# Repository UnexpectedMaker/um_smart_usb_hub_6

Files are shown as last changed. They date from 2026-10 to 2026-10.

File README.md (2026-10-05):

# Smart 6 Port USB Hub

**Automated testing. Automated device control.**

**Designed and made by [Unexpected Maker](https://unexpectedmaker.com) ·
[Get one from the store →](https://unexpectedmaker.com/shop/smarthub)**

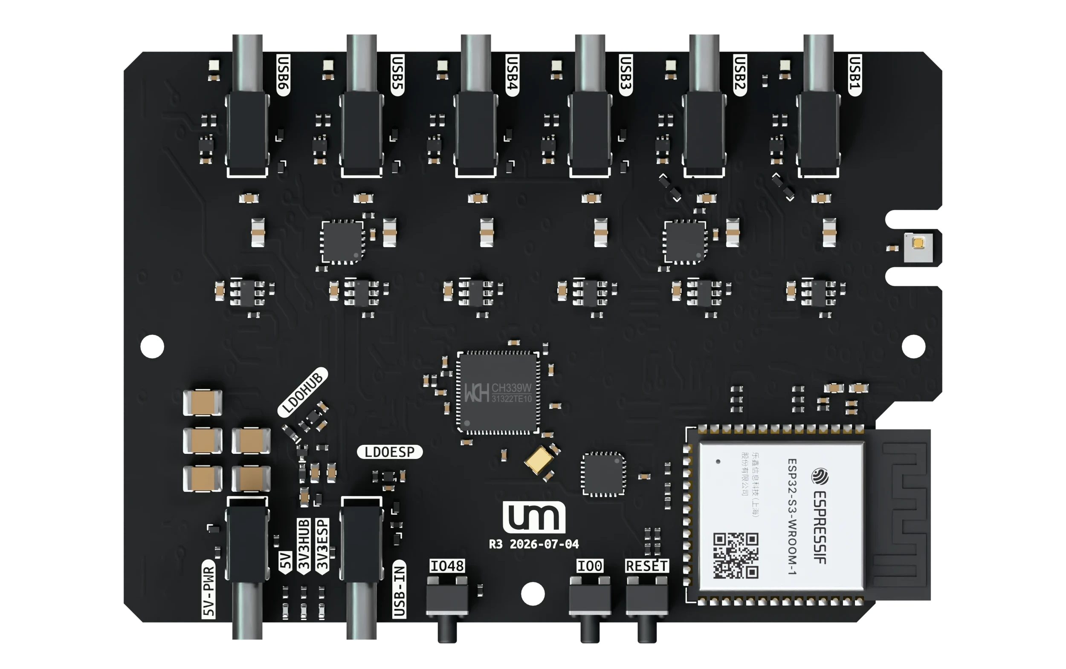
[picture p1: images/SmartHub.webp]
Smart 6 Port USB Hub


Built for developers, test benches and USB devices that need to run unattended.
Smart USB Hub brings repeatable testing and everyday device routines to your
workbench, without the constant plugging, unplugging and reaching for cables.

## What it does

**Power cycling, scripted.** Use the REST API to switch a device's power, read
its voltage, current and power consumption, and check port status from your
test scripts. Repeat a startup test or compare readings across operating states
while the other devices stay powered.

**Every port, scheduled.** Set a different schedule for each port: selected
weekdays, a fixed run time, a chosen stop time or repeating intervals. Rules run
on the hub, so your browser doesn't need to stay open.

**Step in any time.** Open the web interface over Wi-Fi to switch an individual
port or investigate a device. Live readings show what it's drawing; connection
and fault status help you see why it isn't behaving as expected.

## Specifications

| | |
|---|---|
| Downstream | 6 × USB-C · USB 2.0 |
| Upstream | 1 × USB-C · USB 2.0 |
| Controller | ESP32-S3-WROOM-1 · 16 MB flash · 8 MB PSRAM |
| Port power | 5V USB-C input · 3A+ supply |
| 3V3 power | 2 × 3.3V LDOs · headroom for the ESP32-S3, hub chip, peripherals and LEDs |
| Protection | Per-port current limiting and over-current fault detection |
| Monitoring | Per-port voltage, current and power |
| Indicators | Per-port RGB status · power, device presence and faults |
| Environment | Onboard temperature and humidity sensor |
| Buttons | IO48 user button · IO0 / Boot · Reset |

## It's open source

Smart USB Hub is fully open source, so you can see exactly how it works, tweak
it to suit your bench, or build your own. Everything is in this repository:

| Folder | Contents |
|---|---|
| [`firmware/`](firmware/) | The PlatformIO project — building, flashing, first-time Wi-Fi setup and how to use the hub |
| [`hardware/`](hardware/) | KiCad 10 design files: schematic, PCB, footprints, 3D models and interactive BOM |
| [`docs/`](docs/) | Documentation: the [JSON / REST API reference](docs/rest_api.md) and [planned future updates](docs/future_updates.md) |
| [`step/`](step/) | STEP models of the board and the case, the light pipe insert, and the parts list for printing your own case |

Each folder has its own README with the details.

## Optional case

Add the case from the [store](https://unexpectedmaker.com/shop/smarthub) and
your hub goes from bare board to finished desk tool:

- **Matt black ABS** — a 3D printed enclosure that looks right at home on any
  bench
- **Laser cut light pipes** — every port's RGB status still shines through
- **Heat inserts + screws** — proper threads, so it goes together solid
- **Rubber feet** — it stays put when you plug and unplug

Or print your own from the files in [`step/`](step/) — its README covers the
light pipe insert and the screws, inserts and feet you'll need.

## Getting started

If you have a hub, start with **First-time setup** in the
[firmware README](firmware/README.md#first-time-setup). It gets the hub onto
your Wi-Fi so you can use the web interface.

## Licence

Copyright (c) 2026 [Unexpected Maker](https://unexpectedmaker.com).

| Part | Licence |
|---|---|
| Hardware (`hardware/`) and 3D files (`step/`) | [CERN-OHL-S v2](hardware/LICENSE) — strongly reciprocal: if you distribute the design, a modified version, or hardware made from it, you must publish the complete design source under the same licence |
| Firmware (`firmware/`) | [GPL-3.0-or-later](firmware/LICENSE) — use it, change it, put it in your own products; if you distribute it, you must publish the complete firmware source under the same licence. Bundled third-party code keeps its own licence (see the [firmware README](firmware/README.md#third-party-code)) |

Source location: <https://github.com/UnexpectedMaker/um_smart_usb_hub_6>

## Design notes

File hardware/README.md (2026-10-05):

# Hardware

KiCad 10 project for the Unexpected Maker 6 Port Smart USB Hub (R3).

Open `UM 6 Port USB HUB R3/UM 6 Port USB HUB R3.kicad_pro` in KiCad 10 or later.

## Self-contained project

Everything that is not part of a standard KiCad installation is included in the project folder. No external or personal libraries are needed, and there are no absolute paths in any project file.

- **Footprints** – every non-stock footprint used on the board lives in the project library `UM_Hub.pretty`. It is registered through the project `fp-lib-table` using `${KIPRJMOD}`, so KiCad picks it up automatically when the project is opened.
- **3D models** – every non-stock model is in `3d models/` and is referenced relative to the project (`${KIPRJMOD}/3d models/...`). The 0805 resistor model is embedded in its footprint.
- **Stock parts** – the remaining footprints and models come from the default libraries installed with KiCad (`Capacitor_SMD`, `Package_DFN_QFN`, `Package_TO_SOT_SMD`, `RF_Module`, `MountingHole` and the standard `KICAD*_3DMODEL_DIR` models).
- **Symbols** – the schematic carries its own copy of every symbol it uses, so it opens and edits without any external symbol libraries.

## Contents of `UM 6 Port USB HUB R3/`

| Item | What it is |
|---|---|
| `UM 6 Port USB HUB R3.kicad_pro` | KiCad project file |
| `UM 6 Port USB HUB R3.kicad_sch` | Schematic |
| `UM 6 Port USB HUB R3.kicad_pcb` | PCB layout |
| `UM_Hub.pretty/` | Project footprint library (17 footprints) |
| `fp-lib-table` | Registers `UM_Hub` for this project |
| `3d models/` | STEP models for the non-stock parts |
| `bom/ibom.html` | Interactive HTML BOM |

## Manufacturing

If you are getting this board manufactured, the PCB stackup must match the following so that the USB differential pairs are impedance matched.

PCB Stackup: JLC04161H-3313 (Finished thickness 1.56mm ±10%)

90R Diff Pair Impedance:
- Trace 0.1545mm
- Gap 0.232mm
- Co-Planar Clearance 0.194mm

## Licence

Copyright (c) 2026 [Unexpected Maker](https://unexpectedmaker.com).

The hardware design files are licensed under the CERN Open Hardware Licence
Version 2 — Strongly Reciprocal (CERN-OHL-S v2). See [LICENSE](LICENSE).

If you distribute this design, a modified version of it, or hardware made from
it, you must make the complete design source available under the same licence.

Source location: <https://github.com/UnexpectedMaker/um_smart_usb_hub_6>

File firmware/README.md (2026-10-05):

# Smart USB Hub — Firmware

**Designed and made by [Unexpected Maker](https://unexpectedmaker.com).**

Firmware for the Unexpected Maker Smart USB Hub: a 6-port USB 2.0 hub with an
ESP32-S3 that controls and monitors every downstream port.

For each port the hub can:

- switch the port's 5V on and off
- detect a plugged-in device, even with the port's power off
- detect an over-current fault
- measure voltage, current and power
- show the port's state on its own RGB LED

All of it is available from a built-in web page, a JSON API, a serial console
and the button on the hub. Ports can also be switched on a weekly schedule.

## Hardware

| Part | Job |
|---|---|
| ESP32-S3-WROOM-1U (16 MB flash, 8 MB PSRAM) | runs this firmware |
| WCH CH339W | USB 2.0 hub, 1 upstream + 6 downstream USB-C ports |
| TPS2552 ×6 | per-port 5V load switch with over-current fault |
| XL9555 | I/O expander for the 6 power enables and 6 fault lines |
| INA3221 ×2 | voltage / current / power, 3 ports each |
| AHT20 | temperature and humidity |
| WS2812B ×6 | one RGB LED per port |

The pin map is at the top of `src/main.cpp`.

## Version

This is firmware **1.0.0**. The version a hub is running is shown in the web
page's side panel (Firmware), by the `info` serial command, and in the `fw`
field of the JSON API. It's set by `HUB_FW_VERSION` at the top of
`src/main.cpp`.

## Building and flashing

You need [PlatformIO](https://platformio.org/), either the VS Code extension or
the command line. The first build downloads the ESP32 toolchain and libraries.

```sh
pio run                      # build
pio run -t upload            # build and flash over USB
```

### Updating over WiFi

Once the hub is running this firmware and is on your network, you can flash it
without a cable:

```sh
pio run -e ota -t upload
```

This uploads to `usb-hub.local`. If `.local` names don't resolve on your
machine, put the hub's IP address in `upload_port` under `[env:ota]` in
`platformio.ini`.

## Serial console

The hub has a text console over USB. It's how you give a new hub its WiFi
details, and it's always there for checking on the hub or controlling it
without a browser.

### Opening it

The ESP32-S3 is connected to one of the hub's own USB ports, so plugging the
hub's upstream USB-C into your computer makes it appear as a USB serial
device. Open it at **115200 baud** with any serial terminal:

- PlatformIO: `pio device monitor`
- Arduino IDE: Tools → Serial Monitor
- macOS / Linux: `screen /dev/cu.usbmodemXXXX 115200` (your device name will
  differ)

The console echoes what you type and supports backspace. Press Enter to run a
command, and type **`help`** at any time to list them all.

The start-up messages are printed before your computer has finished
connecting, so you'll usually miss them — that's normal. Type **`info`** to
see the hub's full current state.

### Commands

| Command | Does |
|---|---|
| `help` | list the commands |
| `info` | full status: network, time, power rails, devices, every port |
| `port <1-6> on\|off` | switch a port |
| `mon` | each port's voltage, current and power, plus the INA3221 alert lines |
| `set_ssid <name>` | store the WiFi network name |
| `set_pass <password>` | store the WiFi password |
| `wifi` | connect with the stored details |
| `restart` | reboot the hub |

## First-time setup

A new hub has no WiFi details, so its web page isn't reachable yet. You give
it your network once, over the [serial console](#serial-console); after that
everything can be changed from the web page.

You can tell which state it's in at power-up: the six LEDs sweep **red** when
no WiFi details are stored, and **green** when they are.

### 1. Open the serial console

Connect the hub to your computer and open the console as described in
[Opening it](#opening-it).

### 2. Enter your WiFi details

```
set_ssid YourNetworkName
set_pass YourPassword
wifi
```

- `set_ssid` and `set_pass` take everything after the command, so names and
  passwords with spaces work. Both are saved straight away and survive a
  restart.
- `wifi` connects using what you've stored. The hub also connects on its own
  at every power-up from now on.
- The ESP32-S3 only supports **2.4 GHz** WiFi.

### 3. Check it connected

Within a few seconds the console prints lines like:

```
[wifi] connected — IP 192.168.1.50
[ota] ready — http://usb-hub.local/
```

If nothing appears, type `info` and look at the network section. `state`
shows what went wrong — `SSID not found` usually means a typo or a 5 GHz-only
network, `connect failed` usually means a wrong password. Fix it with
`set_ssid` / `set_pass` and run `wifi` again.

### 4. Open the web page

Go to `http://usb-hub.local/`, or the IP address from step 3 if `.local`
names don't work on your computer. From the Settings panel you can change the
WiFi details, use a static address, rename the hub, set your location and
time zone, and adjust the LEDs — no serial console needed.

## Using the hub

### Port LEDs

| LED | Port |
|---|---|
| off | power off, nothing plugged in |
| solid blue | power off, device plugged in |
| pulsing blue | power on, nothing plugged in |
| solid green | power on, device plugged in |
| flashing red | over-current fault |
| solid pink | power on but no 5V supply, device plugged in |
| pulsing pink | power on but no 5V supply, nothing plugged in |

### Button

Each press flips every port to the opposite state.

### Web page

- Turn each port on or off, and see its live voltage, current and power
- Weekly schedules per port: switch off, switch on, on for a duration, on
  until a time, or on for a short burst at a regular interval. A timeline shows
  the week, and entries that clash are flagged.
- Settings: device name, hostname, WiFi (DHCP or static address), location and
  time zone, LED brightness
- Light and dark themes

The page is served by the hub itself and needs no internet connection.

### JSON API

The web page is built on a JSON API that other tools can use too, for example
`GET /api/hub`, `GET /api/ports` and `POST /api/hub/ports?on=1` to switch every
port on. Every endpoint, with full example requests and responses, is in the
[API reference](../docs/rest_api.md).

## Project layout

```
src/
  main.cpp       pin map, LEDs, scheduler, JSON, WiFi/OTA, serial console, setup/loop
  ports/         USBPort — one port's power, fault and device sense
  settings/      HubSettings — everything stored in flash (/settings.json)
  web/           HubWebServer (routes and API) and HubWebUI (the embedded page)
lib/
  UM_INA3221/    INA3221 power monitor driver
  UM_LCA9555/    XL9555 / LCA9555 I/O expander driver
  nlohmann_json/ JSON library (third party)
platformio.ini   build configuration
partitions.csv   flash layout: two app slots for OTA, plus storage for settings
```

## Licence

Copyright (c) 2026 [Unexpected Maker](https://unexpectedmaker.com).

The firmware, including the `UM_INA3221` and `UM_LCA9555` driver libraries, is
released under the **GNU General Public License v3.0 or later** — see
[LICENSE](LICENSE).

You're welcome to use it, change it, and use it in your own products. If you
distribute it — or a product running it, or a modified version — you must make
the complete source of that firmware available under the same licence.

### Third-party code

These keep their own licences:

| Code | Where | Licence |
|---|---|---|
| [nlohmann/json](https://github.com/nlohmann/json) 3.12.0 | `lib/nlohmann_json/json.h` | MIT, Copyright (c) 2013-2025 Niels Lohmann |
| [GitHub Octicons](https://github.com/primer/octicons) | icons in `src/web/HubWebUI.h` | MIT, Copyright (c) GitHub Inc. |
| [Phosphor Icons](https://github.com/phosphor-icons/core) | USB icon in `src/web/HubWebUI.h` | MIT, Copyright (c) 2020 Phosphor Icons |
| [GitHub Primer](https://github.com/primer/primitives) | colour themes in `src/web/HubWebUI.h` | MIT, Copyright (c) GitHub Inc. |
| [modern-normalize](https://github.com/sindresorhus/modern-normalize) | CSS reset in `src/web/HubWebUI.h` | MIT, Copyright (c) Sindre Sorhus |

Libraries downloaded at build time (ESPAsyncWebServer, AsyncTCP, Adafruit
NeoPixel, DHT20 and the Arduino ESP32 core) are under their own licences.

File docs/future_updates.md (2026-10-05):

# Smart USB Hub — Future Updates

Ideas and agreed-but-deferred work. **Nothing here is in firmware 1.0.0.**
Items are described, not designed — the details get agreed before anything is
built.

---

## REST API

### Per-port setters

Agreed shape, not built.

#### POST `/api/ports/{n}?on=&boot=`

Set one port's power and/or its power-on-boot flag. Both parameters optional; at
least one required.

| Param | Values | Effect |
|---|---|---|
| `on` | `0`/`1` | Switch the port now. Runtime only — schedules unaffected |
| `boot` | `0`/`1` | Persist this port's power-on-boot state to flash |

```
curl -X POST 'http://192.168.1.100/api/ports/3?on=1'
curl -X POST 'http://192.168.1.100/api/ports/3?boot=1'
```

`on` and `boot` are deliberately independent: switching a port now shouldn't
silently change what it does at the next boot, and vice versa.

Would respond with the same body as `GET /api/ports/{n}`, read back after
applying.

#### PUT `/api/ports/{n}/schedule`

Replace that **one** port's entire schedule and persist it, using the REST
string-`mode` form.

```
curl -X PUT 'http://192.168.1.100/api/ports/6/schedule' \
  -H 'Content-Type: application/json' \
  -d '{"entries":[{"days":62,"time":"07:20","mode":"on_until","until":"17:00"}]}'
```

Would respond with the same body as `GET /api/ports/{n}/schedule`, read back
after validation, with `invalid`/`invalid_reason` filled in. Omitted fields take
their defaults (`dur:60`, `until:"17:00"`, `every:30`, `allday:true`,
`once:false`, `enabled:true`).

Whole-array replacement is the starting proposal: it keeps client and device in
agreement, and avoids entry IDs on a device with no stable identity for a row.
Whether per-entry add / edit / delete is also wanted is still open.

### Restart endpoint

Restarting is serial-only today (`restart`). A hostname change only takes
effect after a restart, so the web UI and API need a way to do it.

### Consistent error handling

Only `/api/hub/ports` validates its input and returns `400`. Every other write
returns `200` on bad query parameters or malformed JSON and silently changes
nothing, so a client can't tell a rejected write from an applied one without
re-reading.

### Authentication

There is none. Anyone on the network can switch ports, and
`/api/settings/schema` returns the WiFi password in clear text. Needs a scheme
(token header or similar) and the password should stop being sent back.

### Calls from other web pages (CORS)

The hub sends no CORS headers, so a web page served from anywhere else can't
call the API from a browser. Scripts, Node, Home Assistant and the hub's own
page are unaffected. Adding the headers would let people build their own
dashboards in the browser.

### One schedule format

The same schedule data has two representations: a string `mode` on the REST
endpoints, and an integer `mode` plus an `on` boolean on the web-UI endpoints.
Settle on one.

---

## Hub-level schedule

A schedule that acts on the whole hub rather than one port. The paths
`GET` / `PUT /api/hub/schedule` are reserved so nothing else takes them. **Not
designed** — no behaviour is specified or assumed.

---

## Per-port statistics and history

**Not tracked today.** Each port holds only its live enabled / occupied / fault
state — no timestamps or counters — so everything reported is instantaneous.

### Power on/off durations

How long a port has been in its current state, and how long in the previous
one: "Port 3 has been **on** for 4h 12m", "Port 5 has been **off** for 2d 6h",
plus total powered time per port.

To settle before building:
- `millis()` wraps after ~49 days, so durations need 64-bit or wrap-safe maths.
- Is "on" the firmware's enabled flag, or genuinely powered (enabled **and**
  main 5V present)? They differ whenever the 5V supply is missing — the pink
  LED states.
- Does it reset on reboot, or persist?

### Power cycle counts

On and off transitions per port, ideally split by **cause**: button, web UI,
REST API, schedule, or boot state. Fault events per port alongside them — an
over-current that keeps recurring is worth surfacing.

### Device detection counts

Insertions and removals per port, time since the last of each, and total time a
device has been present (separate from time powered).

### Decisions common to all three

- **Persistence** — RAM only (lost on reboot) or written to flash? Flash has a
  limited number of writes, so a persisted counter needs a slow flush interval
  or wear levelling; it can't be written on every change.
- **Reset** — a "clear statistics" action, per port or hub-wide?
- **Where it shows** — new fields on `GET /api/ports/{n}`, a dedicated
  `/stats` endpoint, and where on the web page.
- **Lifetime vs since power-up** — both are useful, at the cost of more storage
  and UI.

---

## Firmware

- **Hostname changes without a restart.** Today the new name only takes effect
  after a restart.
- **Power-on-boot in the web UI.** Which ports come up at boot can only be set
  through the API (`/api/settings`) today; the Settings panel has no control
  for it.
- **Hub IC reset line (IO2).** It's wired to the ESP32-S3 but the firmware
  doesn't use it. Whether the firmware should hold it, or use it to reset the
  hub chip, is undecided.
- **MQTT.** Planned for later; not designed.
- **Drive the port LEDs with RMT directly.** The six LEDs currently go through
  the Adafruit NeoPixel library. Six LEDs on one pin don't need a third-party
  library — talk to the ESP32's RMT peripheral directly and drop the
  dependency.

---

## Web UI

- **Timeline in the light theme.** Days other than today are darkened by 40%,
  which is subtle on the dark theme but turns the light theme's rows into heavy
  grey bars.

---

## Hardware

- **Schematic PDF**, for anyone without KiCad.

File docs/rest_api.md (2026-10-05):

# Smart USB Hub — REST API

The hub has a JSON API over HTTP, so scripts, test rigs and home automation can
do everything the web page does: switch ports, read each port's voltage,
current and power, check for devices and faults, and change settings and
schedules.

Every endpoint below is documented with a **complete example payload** — what
the device actually sends, not an abridged shape. Writes show the request and
the exact response body. Ready-to-use code for curl, Python, JavaScript and Home
Assistant is in [Examples](#examples).

**Contents:** [Getting started](#getting-started) ·
[Conventions](#conventions) · [Endpoint summary](#endpoint-summary) ·
[Reads](#reads) · [Writes](#writes) · [Examples](#examples) ·
[The schedule entry object](#the-schedule-entry-object) ·
[Current limitations](#current-limitations)

---

## Getting started

### The hub's address

The API lives on the same address as the web page:

- **`http://usb-hub.local`** — the default hostname. You can change it in the
  web page's Settings (Device → Hostname); the new name applies after a restart.
- **The hub's IP address** — use this if `.local` names don't resolve on your
  machine. The serial console's `info` command shows it, and so does your
  router.

All the examples here use `http://usb-hub.local`. Swap in your own address.

### No key or login

There's no authentication: like the web page, the API is open to anything on
the same network. Keep the hub on a network you trust.

### Try it

```sh
curl http://usb-hub.local/api/hub
```

You should get back a JSON object with the hub's name, firmware version,
temperature, total current draw and more.

### Which endpoint do I want?

| To… | Use |
|---|---|
| Read the hub as a whole (power, temperature, clock, network) | [`GET /api/hub`](#get-apihub) |
| Read all six ports | [`GET /api/ports`](#get-apiports) |
| Read one port in detail, with its schedule | [`GET /api/ports/{n}`](#get-apiportsn) |
| Switch one port on or off | [`POST /api/port?n=&on=`](#post-apiportn1-6on01) |
| Switch every port on or off | [`POST /api/hub/ports?on=`](#post-apihubportson01) |
| Choose which ports power up at boot | [`POST /api/settings`](#post-apisettings) with `{"ports":{"power_on_boot":[...]}}` |
| Change any other setting | [`POST /api/settings`](#post-apisettings) |
| Replace the schedules | [`POST /api/schedules`](#post-apischedules) |

---

## Conventions

- **Base path**: `/api`
- **Responses**: `application/json`, UTF-8. Always a JSON **object** at the top
  level (never a bare array) so fields can be added without breaking clients.
- **Simple actions** take **query parameters** (easy from `curl`, shell, Home
  Assistant). **Bulk data** (schedules, settings) takes a **JSON body**.
- **Port numbers** are `1..6`, matching the silkscreen and the LEDs.
- **No authentication.** The API is open to anyone on the LAN.
- **Time** is device-local, resolved from the `location` UTC offset + NTP.
  All schedule times are local, 24-hour `"HH:MM"`.
- Floats are emitted with fixed precision: volts 2 dp, mA/mW 1 dp, temperature
  and humidity 1 dp.

### Status codes

| Code | Meaning |
|---|---|
| `200` | OK |
| `400` | Missing or unparseable parameter (only `/api/hub/ports` returns this) |
| `404` | Unknown endpoint, or a port outside `1..6` |

### Error bodies

Unknown path, including a port outside `1..6` (`/api/ports/9`):

```json
{ "error": "not found" }
```

Bad `on` parameter on `/api/hub/ports`:

```json
{ "error": "bad param", "detail": "on must be 0 or 1" }
```

Everything else is lenient: a malformed `/api/port` query, bad JSON on
`/api/schedules`, or bad JSON on `/api/settings` all return `200` and silently
apply nothing. See *Current limitations*.

---

## Endpoint summary

| Method | Path | Purpose |
|---|---|---|
| `GET` | `/api/hub` | Whole-hub snapshot (power, sensors, network, time, devices) |
| `GET` | `/api/ports` | State of all six ports |
| `GET` | `/api/ports/{n}` | One port in detail, including its schedule |
| `GET` | `/api/ports/{n}/schedule` | One port's schedule |
| `GET` | `/api/status` | Combined payload backing the web UI |
| `GET` | `/api/schedules` | All six ports' schedules |
| `GET` | `/api/settings/schema` | Settings structure + current values |
| `POST` | `/api/port?n=&on=` | Switch one port |
| `POST` | `/api/schedules` | Replace all schedules |
| `POST` | `/api/settings` | Update one or more settings groups |
| `POST` | `/api/theme?value=` | Store the UI theme |
| `POST` | `/api/location/detect` | Trigger IP geolocation lookup |
| `POST` | `/api/hub/ports?on=` | Set **all** ports on/off at once |

Static assets, also served from flash: `GET /`, `GET /hub.css`, `GET /hub.js`.

**Two schedule representations exist.** The REST endpoints (`/api/ports/...`)
emit `mode` as a **string** and omit the `on` boolean. The web-UI endpoints
(`/api/status`, `/api/schedules`) emit `mode` as an **integer** alongside `on`.
Both are documented below. Don't mix them.

---

# Reads

## GET `/api/hub`

Everything that isn't per-port.

```
curl http://192.168.1.100/api/hub
```

```json
{
  "name": "Smart USB Hub",
  "fw": "1.0.0",
  "uptime_s": 838,
  "reset_reason": "POWERON",
  "power": {
    "main_5v": true,
    "upstream_5v": true,
    "total_ma": 452.0,
    "total_mw": 2260.0
  },
  "sensors": {
    "temp_c": 30.8,
    "humidity": 29.6,
    "valid": true
  },
  "clock": {
    "synced": true,
    "iso": "2026-08-02T16:33:38+10:00",
    "time": "16:33",
    "date": "Sun 02 Aug 2026",
    "wday": 0,
    "secs": 59618,
    "utc_offset": 10
  },
  "network": {
    "connected": true,
    "ip": "192.168.1.100",
    "ssid": "MyNetwork",
    "rssi": -54,
    "hostname": "usb-hub"
  },
  "devices": {
    "expander": true,
    "ina_1": true,
    "ina_2": true,
    "aht20": true
  },
  "memory": { "heap_free": 209800, "heap_max_block": 163828 },
  "ports_summary": { "count": 6, "powered": 1, "occupied": 0, "faulted": 0 }
}
```

When the clock hasn't synced and WiFi is down, the same request returns:

```json
{
  "name": "Smart USB Hub",
  "fw": "1.0.0",
  "uptime_s": 7,
  "reset_reason": "POWERON",
  "power": { "main_5v": true, "upstream_5v": false, "total_ma": 0.0, "total_mw": 0.0 },
  "sensors": { "temp_c": 0.0, "humidity": 0.0, "valid": false },
  "clock": { "synced": false, "iso": "", "time": "", "date": "", "wday": 0, "secs": 0, "utc_offset": 10 },
  "network": { "connected": false, "ip": "", "ssid": "MyNetwork", "rssi": 0, "hostname": "usb-hub" },
  "devices": { "expander": true, "ina_1": true, "ina_2": true, "aht20": true },
  "memory": { "heap_free": 231044, "heap_max_block": 163828 },
  "ports_summary": { "count": 6, "powered": 0, "occupied": 0, "faulted": 0 }
}
```

**Field notes**

- `power.main_5v` — the downstream 5V rail that actually feeds the ports, from
  the main 5V sense (IO7). `true` = present.
- `power.upstream_5v` — upstream (host-side) USB 5V, from the upstream sense
  (IO6). `true` = present.
- `power.total_ma` / `total_mw` — summed across both INA3221s, counting only
  ports whose monitor is present.
- `sensors.valid` — `false` until the first successful AHT20 read, or forever if
  the sensor is absent. `temp_c` and `humidity` are `0.0` then, not meaningful.
- `clock.synced` — `false` until NTP lands; the other clock fields are empty or
  zero while it is false. `utc_offset` comes from settings and is valid either
  way.
- `network.hostname` — the `device.hostname` setting, lower-cased and stripped
  of anything that isn't a letter, digit or `-`. The hub answers at
  `<hostname>.local`.
- `devices.*` — I2C presence. A `false` here explains why the related readings
  are missing rather than zero.
- `reset_reason` — why the **previous** boot ended: `POWERON`, `SW` (software restart, including after an OTA update), `USB`
  (reset over USB, e.g. flashing), `PANIC`, `TASK_WDT` / `INT_WDT` / `WDT`
  (watchdogs), `BROWNOUT`, `PWR_GLITCH`, `EXT`, `DEEPSLEEP`, `JTAG`, `EFUSE`,
  `CPU_LOCKUP`, `SDIO`, or `UNKNOWN`.

---

## GET `/api/ports`

All six ports. Always six entries, always in port order.

```
curl http://192.168.1.100/api/ports
```

```json
{
  "ports": [
    {
      "n": 1,
      "enabled": false,
      "occupied": false,
      "fault": false,
      "state": "off",
      "monitor": true,
      "volts": 0.00,
      "ma": 0.0,
      "mw": 0.0,
      "schedule": { "count": 0, "next": null }
    },
    {
      "n": 2,
      "enabled": true,
      "occupied": false,
      "fault": false,
      "state": "pulse",
      "monitor": true,
      "volts": 5.07,
      "ma": 0.4,
      "mw": 2.0,
      "schedule": { "count": 0, "next": null }
    },
    {
      "n": 3,
      "enabled": true,
      "occupied": true,
      "fault": true,
      "state": "fault",
      "monitor": true,
      "volts": 4.61,
      "ma": 1980.2,
      "mw": 9129.1,
      "schedule": { "count": 0, "next": null }
    },
    {
      "n": 4,
      "enabled": false,
      "occupied": true,
      "fault": false,
      "state": "blue",
      "monitor": false,
      "volts": 0.00,
      "ma": 0.0,
      "mw": 0.0,
      "schedule": { "count": 0, "next": null }
    },
    {
      "n": 5,
      "enabled": true,
      "occupied": false,
      "fault": false,
      "state": "pinkpulse",
      "monitor": true,
      "volts": 0.02,
      "ma": 0.0,
      "mw": 0.0,
      "schedule": {
        "count": 1,
        "next": { "in_s": 3542, "on": false, "at": "Sun 17:30", "entry": 0 }
      }
    },
    {
      "n": 6,
      "enabled": true,
      "occupied": true,
      "fault": false,
      "state": "green",
      "monitor": true,
      "volts": 5.05,
      "ma": 120.4,
      "mw": 607.9,
      "schedule": {
        "count": 2,
        "next": { "in_s": 82, "on": false, "at": "Sun 16:35", "entry": 0 }
      }
    }
  ]
}
```

**Field notes**

- `enabled` — power switched on by firmware. Not the same as current actually
  flowing: with `main_5v` absent a port can be `enabled` and still dead.
- `occupied` — a device is plugged in (sense line, works with power off).
- `fault` — over-current latched by the TPS2552 for that port.
- `state` — the LED state token, so an API client can mirror the physical LED
  exactly. One of:

  | `state` | LED | Meaning |
  |---|---|---|
  | `off` | dark | not enabled, nothing plugged in |
  | `blue` | solid blue | device present, power off |
  | `green` | solid green | powered, device present |
  | `pulse` | pulsing blue | powered, nothing plugged in |
  | `pink` | solid pink | enabled but **no main 5V**, device present |
  | `pinkpulse` | pulsing pink | enabled but **no main 5V**, no device |
  | `fault` | flashing red | over-current |

- `monitor` — `false` when that port's INA3221 is absent; `volts`/`ma`/`mw` are
  then `0` and should be shown as unavailable, not as real readings.
- `schedule.count` — **live** entries only (enabled and not clashing).
- `schedule.next` — `null` when there is nothing upcoming or the clock isn't
  synced. `in_s` counts down in seconds; `at` is `"Ddd HH:MM"` local; `entry` is
  the index into that port's full schedule array, so a client can highlight which
  rule fires next.

---

## GET `/api/ports/{n}`

One port: everything from `/api/ports`, **plus** `power_on_boot` and the full
schedule entry list.

```
curl http://192.168.1.100/api/ports/6
```

```json
{
  "n": 6,
  "enabled": true,
  "occupied": true,
  "fault": false,
  "state": "green",
  "monitor": true,
  "volts": 5.05,
  "ma": 120.4,
  "mw": 607.9,
  "power_on_boot": false,
  "schedule": {
    "count": 2,
    "next": { "in_s": 82, "on": false, "at": "Sun 16:35", "entry": 0 },
    "entries": [
      {
        "days": 127,
        "time": "07:20",
        "mode": "on_for",
        "dur": 60,
        "until": "17:00",
        "every": 30,
        "allday": true,
        "once": false,
        "enabled": true,
        "invalid": false
      },
      {
        "days": 8,
        "time": "22:00",
        "mode": "off",
        "dur": 60,
        "until": "17:00",
        "every": 30,
        "allday": true,
        "once": false,
        "enabled": true,
        "invalid": true,
        "invalid_reason": "clash"
      }
    ]
  }
}
```

A port with no schedule:

```json
{
  "n": 1,
  "enabled": false,
  "occupied": false,
  "fault": false,
  "state": "off",
  "monitor": true,
  "volts": 0.00,
  "ma": 0.0,
  "mw": 0.0,
  "power_on_boot": false,
  "schedule": { "count": 0, "next": null, "entries": [] }
}
```

`404` with `{ "error": "not found" }` if `n` is outside `1..6`.

---

## GET `/api/ports/{n}/schedule`

Just the schedule for one port — the same `count`, `next` and `entries` as
above, without the live electrical state.

```
curl http://192.168.1.100/api/ports/6/schedule
```

```json
{
  "n": 6,
  "count": 2,
  "next": { "in_s": 82, "on": false, "at": "Sun 16:35", "entry": 0 },
  "entries": [
    {
      "days": 62,
      "time": "07:20",
      "mode": "on_until",
      "dur": 60,
      "until": "17:00",
      "every": 30,
      "allday": true,
      "once": false,
      "enabled": true,
      "invalid": false
    },
    {
      "days": 1,
      "time": "09:00",
      "mode": "on_every",
      "dur": 5,
      "until": "18:00",
      "every": 30,
      "allday": false,
      "once": false,
      "enabled": true,
      "invalid": false
    }
  ]
}
```

Empty schedule:

```json
{ "n": 2, "count": 0, "next": null, "entries": [] }
```

`404` with `{ "error": "not found" }` if `n` is outside `1..6`.

---

## GET `/api/status`

The single payload the web UI polls every second. Everything in one object, with
**short field names** and the integer schedule representation. Separate from the
REST endpoints above — it exists for the page, but it is readable by anything.

```
curl http://192.168.1.100/api/status
```

```json
{
  "name": "Smart USB Hub",
  "fw": "1.0.0",
  "rst": "POWERON",
  "theme": "dark",
  "ip": "192.168.1.100",
  "uptime_s": 838,
  "heap": 209800,
  "maxblk": 163828,
  "main5v": true,
  "upstream5v": true,
  "temp": { "valid": true, "c": 30.8, "h": 29.6 },
  "clock": {
    "synced": true,
    "time": "16:33",
    "date": "Sun 02 Aug 2026",
    "wday": 0,
    "secs": 59618
  },
  "ports": [
    {
      "n": 1, "enabled": false, "occupied": false, "fault": false,
      "state": "off", "mon": true, "v": 0.00, "ma": 0.0, "mw": 0.0, "sched": 0
    },
    {
      "n": 2, "enabled": true, "occupied": false, "fault": false,
      "state": "pulse", "mon": true, "v": 5.07, "ma": 0.4, "mw": 2.0, "sched": 0
    },
    {
      "n": 3, "enabled": true, "occupied": true, "fault": true,
      "state": "fault", "mon": true, "v": 4.61, "ma": 1980.2, "mw": 9129.1, "sched": 0
    },
    {
      "n": 4, "enabled": false, "occupied": true, "fault": false,
      "state": "blue", "mon": false, "v": 0.00, "ma": 0.0, "mw": 0.0, "sched": 0
    },
    {
      "n": 5, "enabled": true, "occupied": false, "fault": false,
      "state": "pinkpulse", "mon": true, "v": 0.02, "ma": 0.0, "mw": 0.0,
      "sched": 1,
      "next": { "in": 3542, "on": false, "at": "Sun 17:30", "i": 0 }
    },
    {
      "n": 6, "enabled": true, "occupied": true, "fault": false,
      "state": "green", "mon": true, "v": 5.05, "ma": 120.4, "mw": 607.9,
      "sched": 2,
      "next": { "in": 82, "on": false, "at": "Sun 16:35", "i": 0 }
    }
  ],
  "total": { "ma": 452.0, "mw": 2260.0 }
}
```

**Differences from the REST endpoints**

| `/api/status` | REST equivalent |
|---|---|
| `rst` | `reset_reason` |
| `mon`, `v` | `monitor`, `volts` |
| `sched` (int) | `schedule.count` |
| `next.in`, `next.i` | `schedule.next.in_s`, `schedule.next.entry` |
| `next` key **absent** when nothing upcoming | `schedule.next` present and `null` |
| `heap`, `maxblk` | `memory.heap_free`, `memory.heap_max_block` |
| `temp.c`, `temp.h` | `sensors.temp_c`, `sensors.humidity` |
| `main5v`, `upstream5v` | `power.main_5v`, `power.upstream_5v` |
| `theme` (UI only) | — |

---

## GET `/api/schedules`

All six ports' schedules in one object, in the **web UI's integer form**: an
`on` boolean plus a numeric `mode`. `ports[0]` is port 1.

```
curl http://192.168.1.100/api/schedules
```

```json
{
  "ports": [
    [],
    [],
    [],
    [],
    [
      {
        "days": 127,
        "time": "08:00",
        "on": true,
        "mode": 1,
        "every": 30,
        "allday": true,
        "dur": 540,
        "until": "17:00",
        "once": false,
        "enabled": true,
        "invalid": false
      }
    ],
    [
      {
        "days": 62,
        "time": "07:20",
        "on": true,
        "mode": 2,
        "every": 30,
        "allday": true,
        "dur": 60,
        "until": "17:00",
        "once": false,
        "enabled": true,
        "invalid": false
      },
      {
        "days": 8,
        "time": "22:00",
        "on": false,
        "mode": 0,
        "every": 30,
        "allday": true,
        "dur": 60,
        "until": "17:00",
        "once": false,
        "enabled": true,
        "invalid": true
      }
    ]
  ]
}
```

A hub with nothing scheduled returns six empty arrays:

```json
{ "ports": [[], [], [], [], [], []] }
```

**`mode` / `on` mapping**

| `on` | `mode` | REST `mode` string |
|---|---|---|
| `false` | `0` | `off` |
| `true` | `0` | `on` |
| `true` | `1` | `on_for` |
| `true` | `2` | `on_until` |
| `true` | `3` | `on_every` |

`invalid` is reported but **never stored** — it is recomputed on every load and
edit. This form does not include `invalid_reason`.

---

## GET `/api/settings/schema`

The structure *and* the current values of every settings group marked visible —
this is what the settings page builds itself from. Groups with an empty `fields`
array are returned but drawn by nothing.

```
curl http://192.168.1.100/api/settings/schema
```

```json
{
  "groups": [
    {
      "name": "device",
      "label": "Device",
      "values": { "device_name": "Smart USB Hub", "hostname": "usb-hub" },
      "fields": [
        { "type": "string", "key": "device_name", "label": "Device name" },
        { "type": "string", "key": "hostname", "label": "Hostname",
          "help": "Reach the hub at <hostname>.local. Takes effect after a restart." }
      ]
    },
    {
      "name": "wifi",
      "label": "WiFi",
      "values": {
        "ssid": "MyNetwork",
        "password": "hunter2",
        "dhcp": true,
        "ip": "",
        "gateway": "",
        "subnet": ""
      },
      "fields": [
        { "type": "string", "key": "ssid", "label": "SSID" },
        { "type": "string", "key": "password", "label": "Password" },
        { "type": "bool", "key": "dhcp", "label": "DHCP",
          "help": "Off = use the static address below. DNS goes to the gateway." },
        { "type": "string", "key": "ip", "label": "Static IP" },
        { "type": "string", "key": "gateway", "label": "Gateway" },
        { "type": "string", "key": "subnet", "label": "Subnet mask" }
      ]
    },
    {
      "name": "location",
      "label": "Location & Time",
      "values": {
        "city": "Melbourne",
        "country": "AU",
        "utc_offset": 10,
        "ntp_server": "pool.ntp.org"
      },
      "fields": [
        { "type": "string", "key": "city", "label": "City" },
        { "type": "string", "key": "country", "label": "Country" },
        { "type": "int", "key": "utc_offset", "label": "UTC offset", "min": -12, "max": 14, "step": 1 },
        { "type": "string", "key": "ntp_server", "label": "NTP server" }
      ]
    },
    {
      "name": "leds",
      "label": "LEDs",
      "values": { "enabled": true, "brightness": 50 },
      "fields": [
        { "type": "bool", "key": "enabled", "label": "Enabled" },
        { "type": "int", "key": "brightness", "label": "Brightness", "min": 0, "max": 255, "step": 5 }
      ]
    },
    {
      "name": "ports",
      "label": "Ports",
      "values": { "power_on_boot": [false, false, false, false, false, true] },
      "fields": []
    }
  ]
}
```

**Field notes**

- **`values.password` is returned in clear text.** Anything on the LAN can read
  the WiFi password from this endpoint.
- Field `type` is one of `bool`, `int`, `string`.
- `min`/`max`/`step` appear only on `int` fields.
- `help` is an optional one-line hint shown under the field.
- Group order follows registration order and is **not guaranteed stable** — key
  off `name`, not position.
- The `schedules` and `website` groups are hidden from this endpoint. Schedules
  have their own endpoints; the theme has `/api/theme`.

---

# Writes

## POST `/api/port?n=<1-6>&on=<0|1>`

Switch one port's 5V. Runtime only — this does not alter schedules, and a
scheduled event will still switch the port at its next occurrence.

```
curl -X POST 'http://192.168.1.100/api/port?n=6&on=1'
```

**Returns the full `/api/status` body**, read back *after* applying, so the
caller sees real device state rather than assuming success:

```json
{
  "name": "Smart USB Hub",
  "fw": "1.0.0",
  "rst": "POWERON",
  "theme": "dark",
  "ip": "192.168.1.100",
  "uptime_s": 841,
  "heap": 209764,
  "maxblk": 163828,
  "main5v": true,
  "upstream5v": true,
  "temp": { "valid": true, "c": 30.8, "h": 29.6 },
  "clock": { "synced": true, "time": "16:33", "date": "Sun 02 Aug 2026", "wday": 0, "secs": 59621 },
  "ports": [
    { "n": 1, "enabled": false, "occupied": false, "fault": false, "state": "off", "mon": true, "v": 0.00, "ma": 0.0, "mw": 0.0, "sched": 0 },
    { "n": 2, "enabled": false, "occupied": false, "fault": false, "state": "off", "mon": true, "v": 0.00, "ma": 0.0, "mw": 0.0, "sched": 0 },
    { "n": 3, "enabled": false, "occupied": false, "fault": false, "state": "off", "mon": true, "v": 0.00, "ma": 0.0, "mw": 0.0, "sched": 0 },
    { "n": 4, "enabled": false, "occupied": false, "fault": false, "state": "off", "mon": true, "v": 0.00, "ma": 0.0, "mw": 0.0, "sched": 0 },
    { "n": 5, "enabled": false, "occupied": false, "fault": false, "state": "off", "mon": true, "v": 0.00, "ma": 0.0, "mw": 0.0, "sched": 0 },
    { "n": 6, "enabled": true, "occupied": true, "fault": false, "state": "green", "mon": true, "v": 5.05, "ma": 120.4, "mw": 607.9, "sched": 0 }
  ],
  "total": { "ma": 120.4, "mw": 607.9 }
}
```

`on` accepts any integer; non-zero is on, `0` is off. If `n` or `on` is missing,
**nothing is switched** and the current status is returned unchanged with `200`.
An `n` outside `1..6` is ignored the same way.

---

## POST `/api/hub/ports?on=<0|1>`

Switch **all six ports** with one request. Runtime only — this does not alter
schedules, and a scheduled event will still switch a port at its next
occurrence.

`on` accepts `1`/`0`, `true`/`false` or `on`/`off`.

```
curl -X POST 'http://192.168.1.100/api/hub/ports?on=1'      # everything on
curl -X POST 'http://192.168.1.100/api/hub/ports?on=0'      # everything off
```

**Returns the same body as `GET /api/ports`**, read back *after* switching:

```json
{
  "ports": [
    { "n": 1, "enabled": true, "occupied": false, "fault": false, "state": "pulse",
      "monitor": true, "volts": 5.07, "ma": 0.4, "mw": 2.0,
      "schedule": { "count": 0, "next": null } },
    { "n": 2, "enabled": true, "occupied": false, "fault": false, "state": "pulse",
      "monitor": true, "volts": 5.07, "ma": 0.3, "mw": 1.5,
      "schedule": { "count": 0, "next": null } },
    { "n": 3, "enabled": true, "occupied": false, "fault": false, "state": "pulse",
      "monitor": true, "volts": 5.06, "ma": 0.4, "mw": 2.0,
      "schedule": { "count": 0, "next": null } },
    { "n": 4, "enabled": true, "occupied": false, "fault": false, "state": "pulse",
      "monitor": true, "volts": 5.07, "ma": 0.3, "mw": 1.5,
      "schedule": { "count": 0, "next": null } },
    { "n": 5, "enabled": true, "occupied": false, "fault": false, "state": "pulse",
      "monitor": true, "volts": 5.06, "ma": 0.4, "mw": 2.0,
      "schedule": { "count": 0, "next": null } },
    { "n": 6, "enabled": true, "occupied": true, "fault": false, "state": "green",
      "monitor": true, "volts": 5.05, "ma": 120.4, "mw": 607.9,
      "schedule": { "count": 2,
        "next": { "in_s": 82, "on": false, "at": "Sun 16:35", "entry": 0 } } }
  ]
}
```

A missing or unparseable `on` returns `400` and switches nothing:

```json
{ "error": "bad param", "detail": "on must be 0 or 1" }
```

> This is **not** the same as the user button, which flips each port to its
> opposite state — a mixed set stays mixed. This endpoint drives all six to the
> same state.

---

## POST `/api/schedules`

Replaces **all six ports'** schedules in one shot and persists them to flash.
Uses the integer `on`/`mode` form.

```
curl -X POST 'http://192.168.1.100/api/schedules' \
  -H 'Content-Type: application/json' \
  -d '{"ports":[[],[],[],[],[],[
        {"days":62,"time":"07:20","on":true,"mode":2,"until":"17:00",
         "dur":60,"every":30,"allday":true,"once":false,"enabled":true}
      ]]}'
```

The response is the **saved** set, read back from the device after validation —
so `invalid` tells you which rules it will refuse to act on:

```json
{
  "ports": [
    [],
    [],
    [],
    [],
    [],
    [
      {
        "days": 62,
        "time": "07:20",
        "on": true,
        "mode": 2,
        "every": 30,
        "allday": true,
        "dur": 60,
        "until": "17:00",
        "once": false,
        "enabled": true,
        "invalid": false
      }
    ]
  ]
}
```

- A rule marked `invalid` is **not an HTTP error** — it is stored and reported,
  matching how the web UI flags a bad row.
- Omitted fields fall back to their defaults (`days:0`, `time:"00:00"`,
  `on:false`, `mode:0`, `dur:60`, `until:"17:00"`, `every:30`, `allday:true`,
  `once:false`, `enabled:true`).
- **All six arrays are required.** The body must carry `ports` with exactly six
  entries; a shorter array is rejected outright and nothing is saved. Send empty
  arrays for the ports you aren't changing — this is a whole-hub replace, so
  omitting a port's entries deletes them.
- **Malformed or rejected JSON returns `200` with the unchanged current set** and
  nothing is saved. Compare the response to what you sent to tell the difference.

---

## POST `/api/settings`

Partial update: send only the groups and keys you want changed. Each named group
is updated, its change handler fires (so e.g. a new `utc_offset` re-applies the
timezone immediately), then everything is saved to flash.

```
curl -X POST 'http://192.168.1.100/api/settings' \
  -H 'Content-Type: application/json' \
  -d '{"leds":{"brightness":120},"location":{"utc_offset":10,"city":"Melbourne"}}'
```

```json
{ "ok": true }
```

- The response is **always** `{"ok":true}`, even for unknown group names, and
  even for malformed JSON — in which case nothing is written. Re-read
  `/api/settings/schema` to confirm what actually landed.
- Group names and keys match `/api/settings/schema` exactly.
- Keys you leave out keep their current values.

---

## POST `/api/theme?value=<dark|light>`

Stores the web UI theme and saves it to flash. Returned by `/api/status` as
`theme`.

```
curl -X POST 'http://192.168.1.100/api/theme?value=light'
```

```json
{ "ok": true }
```

A missing `value` parameter changes nothing and still returns `{"ok":true}`.

---

## POST `/api/location/detect`

Requests a one-shot IP geolocation lookup that fills `city`, `country` and
`utc_offset`. The response only confirms the request was **queued** — the
lookup itself runs in the main loop, never in the web handler.

```
curl -X POST 'http://192.168.1.100/api/location/detect'
```

```json
{ "ok": true }
```

Poll `/api/settings/schema` (or `/api/hub` for `clock.utc_offset`) a couple of
seconds later to see the result. There is no endpoint that reports whether the
lookup succeeded.

---

# Examples

The same jobs in four ways: **curl** for the command line and shell scripts,
**Python** and **JavaScript** for test scripts and tools, and **Home Assistant**
for home automation.

Every example uses `http://usb-hub.local` — swap in your hub's address if
yours is different.

## curl

### Read

```sh
# The hub as a whole: power, temperature, clock, network, devices
curl http://usb-hub.local/api/hub

# All six ports
curl http://usb-hub.local/api/ports

# One port in detail, including its schedule
curl http://usb-hub.local/api/ports/3
```

With [`jq`](https://jqlang.org/) installed you can pull out just what you need:

```sh
# Current draw of every port, one per line
curl -s http://usb-hub.local/api/ports | jq -r '.ports[] | "port \(.n): \(.ma) mA"'

# Is port 2 powered?
curl -s http://usb-hub.local/api/ports/2 | jq .enabled

# Temperature
curl -s http://usb-hub.local/api/hub | jq .sensors.temp_c
```

### Switch ports

```sh
# Port 3 on, then off
curl -X POST 'http://usb-hub.local/api/port?n=3&on=1'
curl -X POST 'http://usb-hub.local/api/port?n=3&on=0'

# Every port on, then off
curl -X POST 'http://usb-hub.local/api/hub/ports?on=1'
curl -X POST 'http://usb-hub.local/api/hub/ports?on=0'
```

### Power-cycle a port

```sh
#!/bin/sh
# Power-cycle one port: off, wait, on.   Usage: ./cycle.sh 3
HUB=http://usb-hub.local
curl -s -X POST "$HUB/api/port?n=$1&on=0" > /dev/null
sleep 2
curl -s -X POST "$HUB/api/port?n=$1&on=1" > /dev/null
```

### Change settings

```sh
# Ports 1 and 2 power up at boot, the rest stay off
curl -X POST http://usb-hub.local/api/settings \
  -H 'Content-Type: application/json' \
  -d '{"ports":{"power_on_boot":[true,true,false,false,false,false]}}'

# Dim the LEDs
curl -X POST http://usb-hub.local/api/settings \
  -H 'Content-Type: application/json' \
  -d '{"leds":{"brightness":20}}'
```

`power_on_boot` needs all six values, port 1 first.

## Python

Uses the [`requests`](https://requests.readthedocs.io/) library
(`pip install requests`).

```python
import time
import requests

HUB = "http://usb-hub.local"  # or the hub's IP, e.g. "http://192.168.1.50"

def hub_status():
    """The hub as a whole: power, temperature, clock, network, devices."""
    r = requests.get(f"{HUB}/api/hub", timeout=5)
    r.raise_for_status()
    return r.json()

def ports():
    """All six ports, port 1 first."""
    r = requests.get(f"{HUB}/api/ports", timeout=5)
    r.raise_for_status()
    return r.json()["ports"]

def port(n):
    """One port (1-6) in detail, including its schedule."""
    r = requests.get(f"{HUB}/api/ports/{n}", timeout=5)
    r.raise_for_status()
    return r.json()

def set_port(n, on):
    """Switch port n (1-6) on or off."""
    r = requests.post(f"{HUB}/api/port", params={"n": n, "on": int(on)}, timeout=5)
    r.raise_for_status()

def set_all_ports(on):
    """Switch every port on or off. Returns the ports as read back afterwards."""
    r = requests.post(f"{HUB}/api/hub/ports", params={"on": int(on)}, timeout=5)
    r.raise_for_status()
    return r.json()["ports"]

def power_cycle(n, off_seconds=2):
    """Turn a port off, wait, and turn it back on."""
    set_port(n, False)
    time.sleep(off_seconds)
    set_port(n, True)

def set_power_on_boot(flags):
    """Which ports power up at boot: six booleans, port 1 first."""
    r = requests.post(f"{HUB}/api/settings",
                      json={"ports": {"power_on_boot": flags}}, timeout=5)
    r.raise_for_status()

if __name__ == "__main__":
    hub = hub_status()
    print(f"{hub['name']}  firmware {hub['fw']}  "
          f"{hub['sensors']['temp_c']} °C  {hub['power']['total_ma']:.0f} mA total")

    for p in ports():
        power = "ON " if p["enabled"] else "off"
        device = "device" if p["occupied"] else "empty"
        fault = "  FAULT" if p["fault"] else ""
        reading = f"{p['volts']:.2f} V  {p['ma']:6.1f} mA" if p["monitor"] else "no monitor"
        print(f"port {p['n']}: {power}  {device:6}  {reading}{fault}")
```

### Log a device's power draw

Watch what a device draws over time — through its start-up, or across its
operating states — while the other ports stay powered:

```python
def log_power(n, seconds=30, interval=0.5):
    """Print port n's voltage, current and power every `interval` seconds."""
    end = time.time() + seconds
    while time.time() < end:
        p = port(n)
        print(f"{time.strftime('%H:%M:%S')}  {p['volts']:5.2f} V  "
              f"{p['ma']:7.1f} mA  {p['mw']:7.1f} mW")
        time.sleep(interval)

# Power-cycle port 3 and capture its start-up
set_port(3, False)
time.sleep(2)
set_port(3, True)
log_power(3, seconds=20)
```

### Repeat a startup test

```python
def startup_test(n, runs=10, settle=5, threshold_ma=50):
    """Power-cycle port n `runs` times and check the device comes up drawing
    at least `threshold_ma` after `settle` seconds."""
    passed = 0
    for i in range(1, runs + 1):
        power_cycle(n)
        time.sleep(settle)
        p = port(n)
        ok = p["occupied"] and not p["fault"] and p["ma"] >= threshold_ma
        passed += ok
        print(f"run {i}: {'pass' if ok else 'FAIL'}  {p['ma']:.1f} mA")
    print(f"{passed}/{runs} passed")
```

## JavaScript

Uses the built-in `fetch`, so it runs in **Node.js 18 or later** with nothing to
install. Save it as `hub.mjs` and run `node hub.mjs`.

```js
const HUB = "http://usb-hub.local"; // or the hub's IP, e.g. "http://192.168.1.50"

async function api(path, method = "GET", body) {
  const res = await fetch(HUB + path, {
    method,
    headers: body ? { "Content-Type": "application/json" } : undefined,
    body: body ? JSON.stringify(body) : undefined,
  });
  if (!res.ok) throw new Error(`${method} ${path}: HTTP ${res.status}`);
  return res.json();
}

const hubStatus = () => api("/api/hub");
const ports = async () => (await api("/api/ports")).ports;
const port = (n) => api(`/api/ports/${n}`);
const setPort = (n, on) => api(`/api/port?n=${n}&on=${on ? 1 : 0}`, "POST");
const setAllPorts = (on) => api(`/api/hub/ports?on=${on ? 1 : 0}`, "POST");
const setPowerOnBoot = (flags) => api("/api/settings", "POST", { ports: { power_on_boot: flags } });
const sleep = (ms) => new Promise((resolve) => setTimeout(resolve, ms));

async function powerCycle(n, offMs = 2000) {
  await setPort(n, false);
  await sleep(offMs);
  await setPort(n, true);
}

const hub = await hubStatus();
console.log(`${hub.name}  firmware ${hub.fw}  ${hub.sensors.temp_c} °C  ${hub.power.total_ma} mA total`);

for (const p of await ports()) {
  const reading = p.monitor ? `${p.volts.toFixed(2)} V  ${p.ma.toFixed(1)} mA` : "no monitor";
  console.log(`port ${p.n}: ${p.enabled ? "ON " : "off"}  ${p.occupied ? "device" : "empty "}  ${reading}${p.fault ? "  FAULT" : ""}`);
}

await powerCycle(3);
```

**From a web page:** the hub doesn't send CORS headers, so a page served from
anywhere else can't call the API from a browser — the browser blocks it. Call it
from Node (as above), from your own server, or from a page served by the hub
itself.

## Home Assistant

Home Assistant talks to the hub with its built-in
[RESTful](https://www.home-assistant.io/integrations/rest/),
[RESTful Command](https://www.home-assistant.io/integrations/rest_command/) and
[Template](https://www.home-assistant.io/integrations/template/) integrations —
nothing to install. Add these to `configuration.yaml`, then restart Home
Assistant.

If Home Assistant can't resolve `usb-hub.local`, use the hub's IP address.

### 1. Commands to switch ports

```yaml
rest_command:
  usb_hub_port:
    url: "http://usb-hub.local/api/port?n={{ port }}&on={{ power }}"
    method: post
  usb_hub_all_ports:
    url: "http://usb-hub.local/api/hub/ports?on={{ power }}"
    method: post
```

The parameter is called `power` rather than `on`, because YAML reads a bare
`on` as `true`.

Call them from any automation or script:

```yaml
- action: rest_command.usb_hub_port
  data:
    port: 3
    power: 1        # 1 = on, 0 = off
- action: rest_command.usb_hub_all_ports
  data:
    power: 0
```

### 2. Sensors

Hub-wide readings, plus each port's power, device, fault and current. Port 1
is shown; copy its four entries for ports 2–6, changing the name and the index
(`ports[1]` for port 2, through `ports[5]` for port 6).

```yaml
rest:
  - resource: http://usb-hub.local/api/hub
    scan_interval: 30
    sensor:
      - name: "USB Hub Temperature"
        unique_id: usb_hub_temperature
        value_template: "{{ value_json.sensors.temp_c }}"
        availability: "{{ value_json.sensors.valid }}"
        unit_of_measurement: "°C"
        device_class: temperature
        state_class: measurement
      - name: "USB Hub Humidity"
        unique_id: usb_hub_humidity
        value_template: "{{ value_json.sensors.humidity }}"
        availability: "{{ value_json.sensors.valid }}"
        unit_of_measurement: "%"
        device_class: humidity
        state_class: measurement
      - name: "USB Hub Total Current"
        unique_id: usb_hub_total_current
        value_template: "{{ value_json.power.total_ma }}"
        unit_of_measurement: "mA"
        device_class: current
        state_class: measurement
      - name: "USB Hub Total Power"
        unique_id: usb_hub_total_power
        value_template: "{{ (value_json.power.total_mw / 1000) | round(2) }}"
        unit_of_measurement: "W"
        device_class: power
        state_class: measurement
    binary_sensor:
      - name: "USB Hub 5V Supply"
        unique_id: usb_hub_5v_supply
        value_template: "{{ value_json.power.main_5v }}"
        device_class: power

  - resource: http://usb-hub.local/api/ports
    scan_interval: 5
    binary_sensor:
      - name: "USB Hub Port 1 Power"
        unique_id: usb_hub_port_1_power
        value_template: "{{ value_json.ports[0].enabled }}"
        device_class: power
      - name: "USB Hub Port 1 Device"
        unique_id: usb_hub_port_1_device
        value_template: "{{ value_json.ports[0].occupied }}"
        device_class: plug
      - name: "USB Hub Port 1 Fault"
        unique_id: usb_hub_port_1_fault
        value_template: "{{ value_json.ports[0].fault }}"
        device_class: problem
      # ... ports 2-6
    sensor:
      - name: "USB Hub Port 1 Current"
        unique_id: usb_hub_port_1_current
        value_template: "{{ value_json.ports[0].ma }}"
        availability: "{{ value_json.ports[0].monitor }}"
        unit_of_measurement: "mA"
        device_class: current
        state_class: measurement
      # ... ports 2-6
```

### 3. A switch for each port

A proper on/off switch per port, built from the command and the power sensor
above. After switching, it refreshes the sensor straight away instead of
waiting for the next poll. Port 1 is shown; copy it for ports 2–6.

```yaml
template:
  - switch:
      - name: "USB Hub Port 1"
        unique_id: usb_hub_port_1
        state: "{{ is_state('binary_sensor.usb_hub_port_1_power', 'on') }}"
        turn_on:
          - action: rest_command.usb_hub_port
            data: { port: 1, power: 1 }
          - action: homeassistant.update_entity
            target: { entity_id: binary_sensor.usb_hub_port_1_power }
        turn_off:
          - action: rest_command.usb_hub_port
            data: { port: 1, power: 0 }
          - action: homeassistant.update_entity
            target: { entity_id: binary_sensor.usb_hub_port_1_power }
      # ... ports 2-6
```

### 4. Automations

```yaml
automation:
  # Power-cycle the device on port 3 every night
  - alias: "USB Hub - nightly power-cycle of port 3"
    triggers:
      - trigger: time
        at: "03:00:00"
    actions:
      - action: switch.turn_off
        target: { entity_id: switch.usb_hub_port_3 }
      - delay: "00:00:05"
      - action: switch.turn_on
        target: { entity_id: switch.usb_hub_port_3 }

  # Everything off when the last person leaves
  - alias: "USB Hub - all off when away"
    triggers:
      - trigger: state
        entity_id: zone.home
        to: "0"
    actions:
      - action: rest_command.usb_hub_all_ports
        data: { power: 0 }

  # Tell me when a port trips its over-current protection
  - alias: "USB Hub - port fault"
    triggers:
      - trigger: state
        entity_id:
          - binary_sensor.usb_hub_port_1_fault
          - binary_sensor.usb_hub_port_2_fault
          - binary_sensor.usb_hub_port_3_fault
          - binary_sensor.usb_hub_port_4_fault
          - binary_sensor.usb_hub_port_5_fault
          - binary_sensor.usb_hub_port_6_fault
        to: "on"
    actions:
      - action: persistent_notification.create
        data:
          title: "USB hub fault"
          message: "{{ trigger.to_state.name }}: over-current on that port."
```

The hub's own schedules (set on its web page) run on the hub itself, so they
keep working whether Home Assistant is running or not. Use Home Assistant for
anything that depends on the rest of your home.

---

# The schedule entry object

One entry is **one rule**. A port's schedule is an ordered array of them.

| Field | Type | Meaning |
|---|---|---|
| `days` | int | Weekday bitmask. **bit0 = Sunday** … bit6 = Saturday. `127` = every day, `62` = Mon–Fri, `65` = weekend |
| `time` | `"HH:MM"` | When it fires (local). For `on_every` + `allday:false` this is the window **start** |
| `mode` | string / int | REST: `off` · `on` · `on_for` · `on_until` · `on_every`. Web UI: `on` bool + `mode` `0..3` |
| `dur` | int | Minutes. On-time for `on_for`, and the pulse length for `on_every` |
| `until` | `"HH:MM"` | End time for `on_until`; window **stop** for `on_every` when `allday:false` |
| `every` | int | Repeat interval in minutes for `on_every`. Minimum **30** |
| `allday` | bool | `on_every` only: repeat all day, or only between `time` and `until` |
| `once` | bool | Fire at the next occurrence, then **disable itself** (kept in the list, re-armable) |
| `enabled` | bool | Row on/off. Disabled rows are ignored but retained |
| `invalid` | bool | **Read-only.** Set by the device when the rule contradicts another or itself |
| `invalid_reason` | string | **Read-only**, REST form only, present only when `invalid` |

`dur`, `until` and `every` are **always stored**, whatever the mode. Switching
mode never discards another mode's value.

**Modes**

| `mode` | Behaviour |
|---|---|
| `off` | Switch the port off at `time` |
| `on` | Switch on at `time`, open-ended (stays on until something else turns it off) |
| `on_for` | On at `time`, off `dur` minutes later. May cross midnight |
| `on_until` | On at `time`, off at `until`. Stores the **end time**, so editing `time` doesn't drag the end. Crossing midnight is fine (`22:00`→`06:00` = 8h) |
| `on_every` | Repeating pulse: on for `dur`, every `every` minutes. `allday:true` = all day on each selected day; `allday:false` = only between `time` and `until` |

**`invalid_reason` values**

| Value | Cause |
|---|---|
| `clash` | Same `time` and a shared day as another entry. On ON vs OFF the OFF loses; two identical actions invalidate the later one |
| `inside_window` | Fires strictly inside another entry's `on_for` / `on_until` window |
| `ends_at_start` | `on_until` ending at its own start time |
| `interval_too_short` | `on_every` with `every` below 30 |
| `duration_exceeds_interval` | `on_every` whose `dur` doesn't fit inside `every` |
| `window_ends_at_start` | `on_every` window starting and stopping at the same time |

> The firmware expands every entry into discrete switch **events** across the
> week. Port state at any instant is "whatever the most recent past event said",
> which is how overlapping rules resolve deterministically — including after a
> reboot, where the device replays to the correct current state.

---

# Current limitations

How the API behaves in firmware 1.0.0. Planned fixes are in
[future_updates.md](future_updates.md).

1. **Inconsistent error handling.** Only `/api/hub/ports` validates its
   parameter and returns `400`. Everywhere else, bad query params and malformed
   JSON bodies return `200` and silently change nothing, so a client can't tell a
   rejected write from an applied one without re-reading.
2. **No authentication.** Anyone on the LAN can switch ports, and
   `/api/settings/schema` returns the WiFi password in clear text.
3. **Few REST setters.** Apart from `/api/hub/ports`, the writes are the ones
   the web UI uses: `/api/port`, `/api/schedules` and `/api/settings` (which
   also sets `power_on_boot`). There are no per-port REST setters yet.
4. **No restart endpoint.** Restarting is serial-only (`restart`) — and a
   hostname change only takes effect after a restart.
5. **Two schedule representations** (string `mode` vs integer `mode` + `on`)
   for the same data.

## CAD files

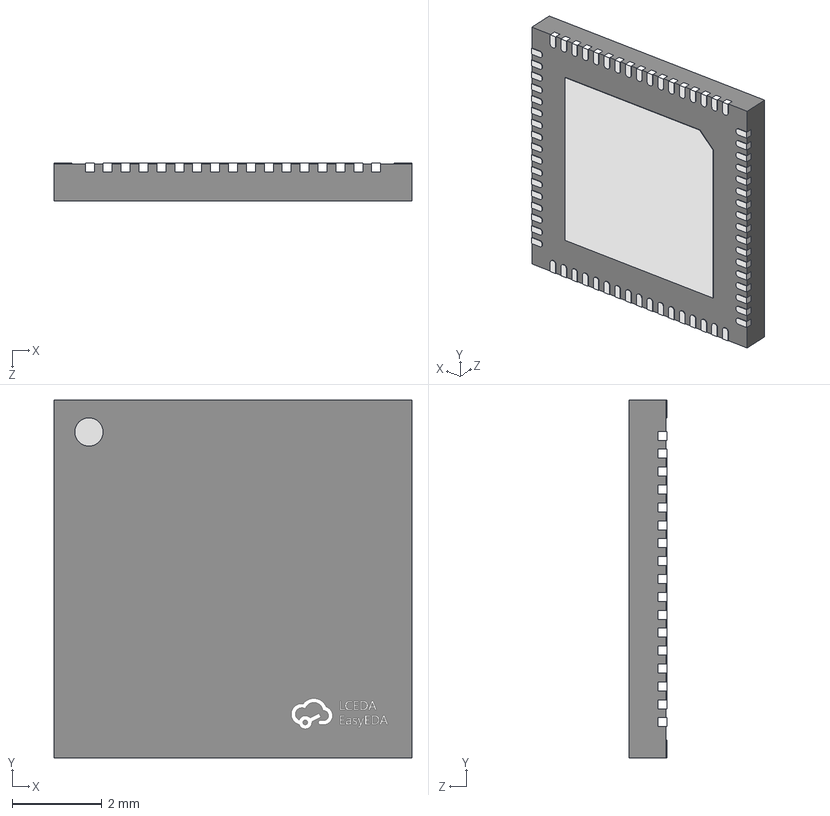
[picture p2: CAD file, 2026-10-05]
hardware/UM 6 Port USB HUB R3/3d models/QFN-68_L8.0-W8.0-P0.40-BL-EP5.5.step
8.00 x 8.00 x 0.851 mm

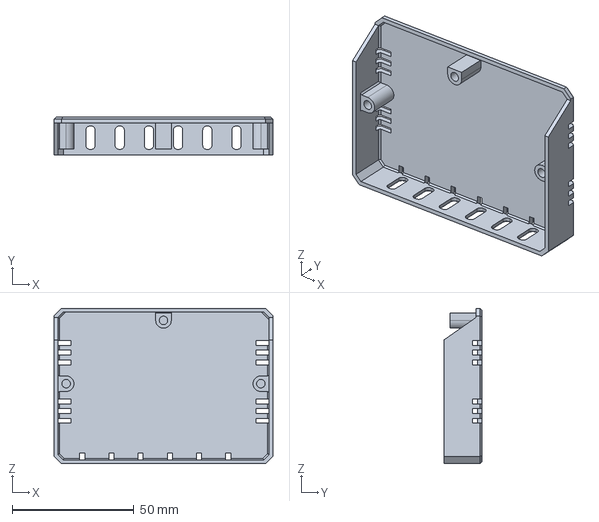
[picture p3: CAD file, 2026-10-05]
step/CASE/USB 6 Port Smart Hub Case Top.step
90.0 x 15.8 x 63.9 mm

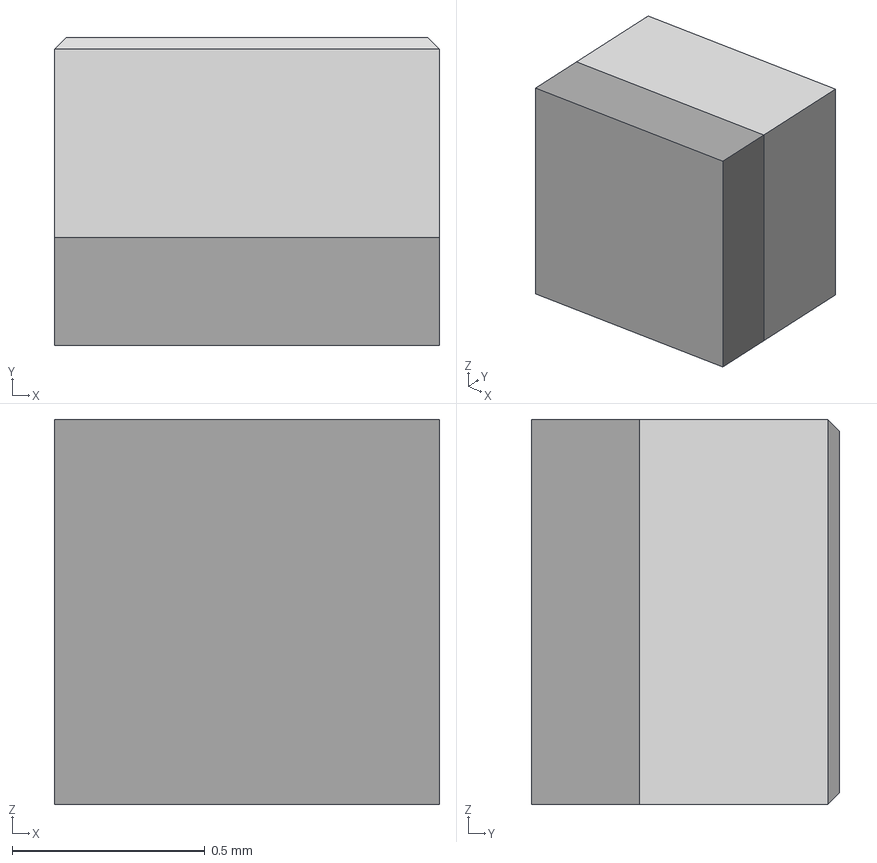
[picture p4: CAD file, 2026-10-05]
hardware/UM 6 Port USB HUB R3/3d models/RGB_LED_1010.step
1.00 x 0.8 x 1.00 mm

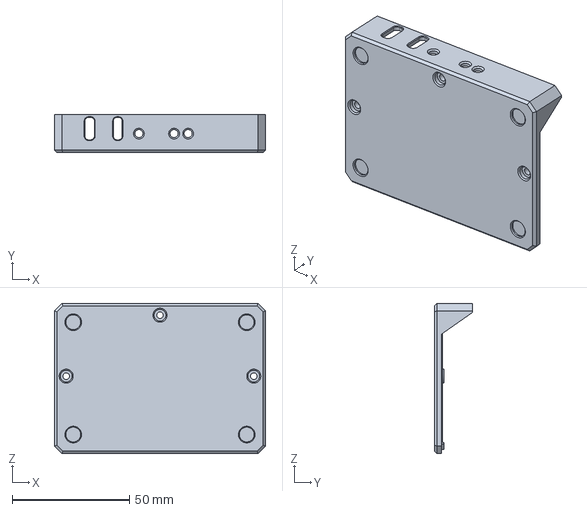
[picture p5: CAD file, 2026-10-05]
step/CASE/USB 6 Port Smart Hub Case Bottom.step
90.0 x 16.2 x 64.0 mm

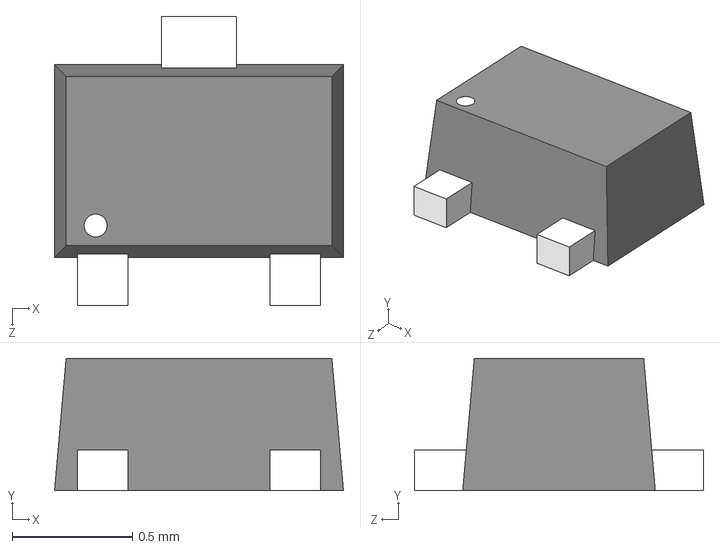
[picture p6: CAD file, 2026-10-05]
hardware/UM 6 Port USB HUB R3/3d models/SOT-723.STEP
1.20 x 0.55 x 1.20 mm

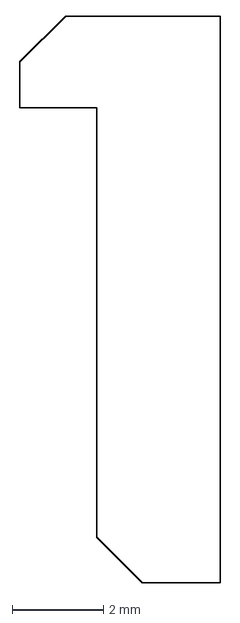
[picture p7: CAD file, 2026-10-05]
step/CASE/Light_Pipe_Insert.dxf
4.38 x 12.4 mm

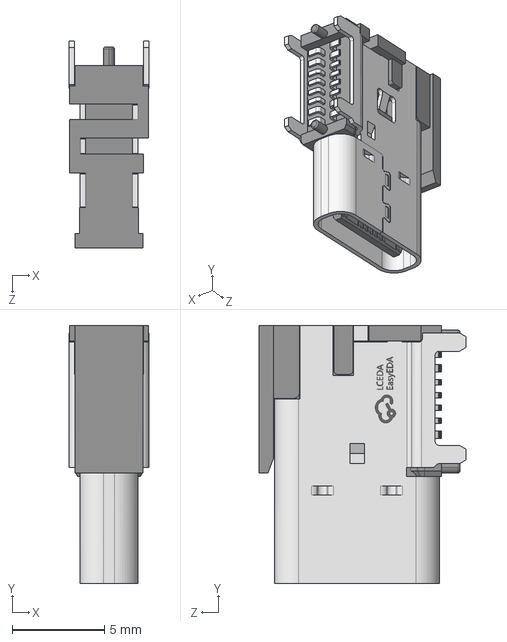
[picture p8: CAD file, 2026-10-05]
hardware/UM 6 Port USB HUB R3/3d models/CONN-SMD_GT-USB-7094A.step
4.36 x 14.0 x 11.2 mm

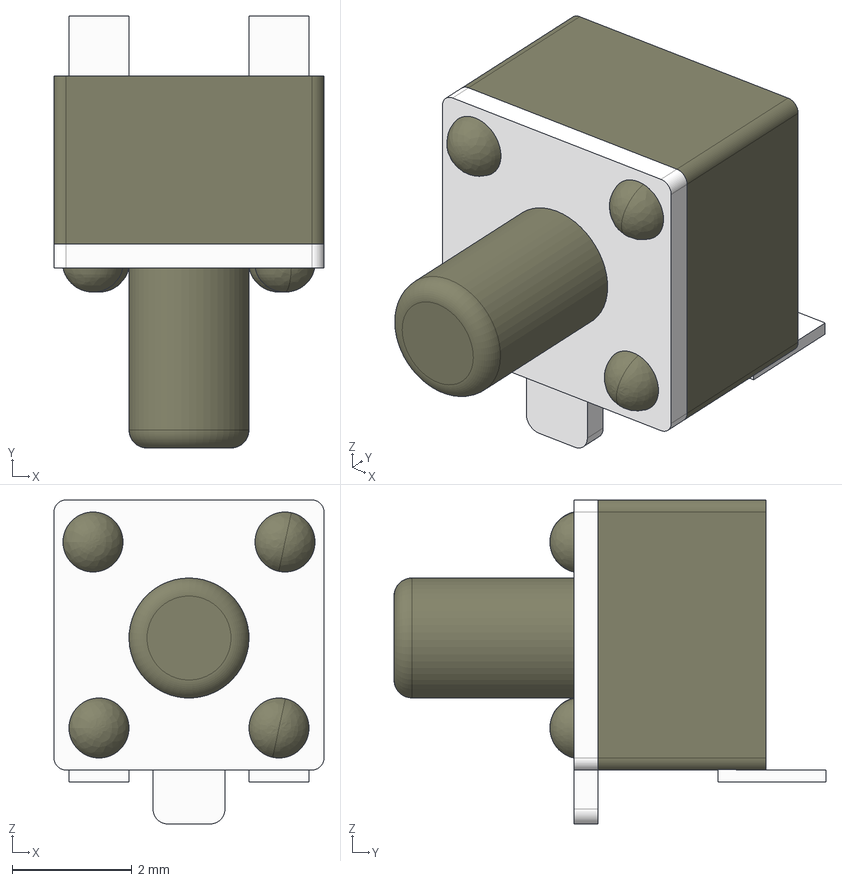
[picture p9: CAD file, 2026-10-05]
hardware/UM 6 Port USB HUB R3/3d models/Side_switch v7.step
4.50 x 7.20 x 5.40 mm

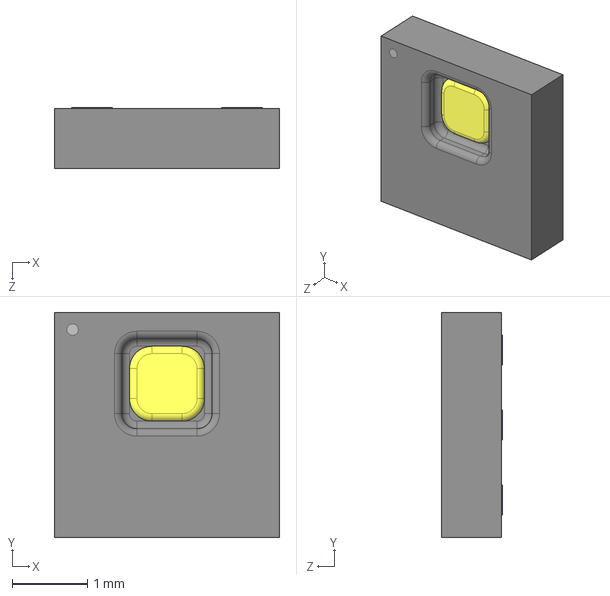
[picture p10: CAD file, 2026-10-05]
hardware/UM 6 Port USB HUB R3/3d models/SENSOR-SMD_L3.0-W3.0-P1.00-BL.step
3.00 x 3.00 x 0.81 mm

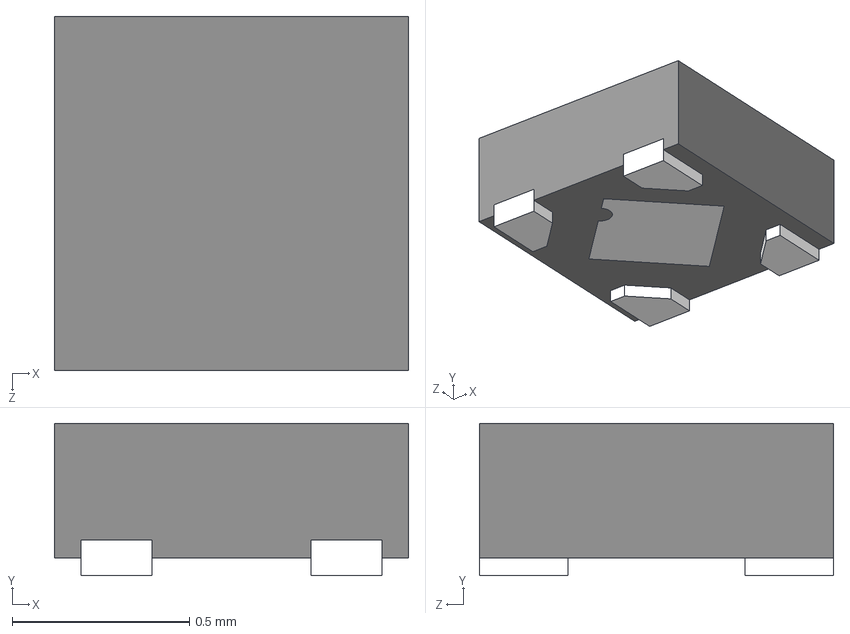
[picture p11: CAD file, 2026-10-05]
hardware/UM 6 Port USB HUB R3/3d models/NCP170AMX170TCG.STEP
1.00 x 0.43 x 1.00 mm

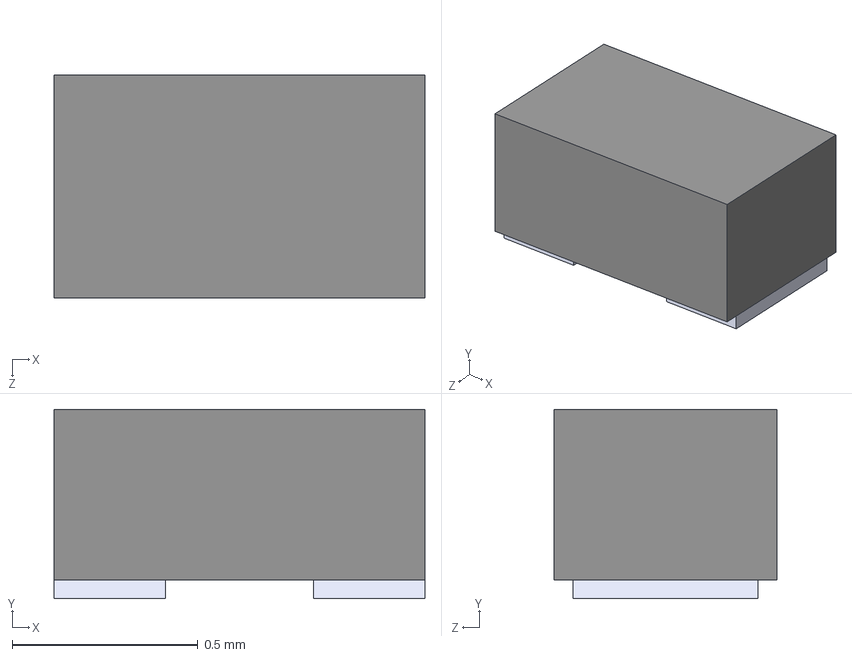
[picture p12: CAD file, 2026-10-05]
hardware/UM 6 Port USB HUB R3/3d models/TVS_DFN1006.step
1.00 x 0.51 x 0.6 mm

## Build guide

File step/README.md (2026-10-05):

# 3D files

STEP models of the Smart USB Hub board and its case, ready to print or remix.
Most CAD tools open STEP files directly.

| File | What it is |
|---|---|
| `UM 6 Port USB HUB R3.step` | The R3 board — use it to design your own case or mount |
| `CASE/USB 6 Port Smart Hub Case Top.step` | Case top |
| `CASE/USB 6 Port Smart Hub Case Bottom.step` | Case bottom |
| `CASE/Light_Pipe_Insert.dxf` | Light pipe insert that carries each port's RGB LED through the case |

The KiCad project for the board is in [`../hardware`](../hardware/).

## Printing your own case

The case from the [Unexpected Maker store](https://unexpectedmaker.com/shop/smarthub)
is 3D printed in matt black ABS. Print the top and bottom from the STEP files
in `CASE/`.

### Light pipe insert

`Light_Pipe_Insert.dxf` is a 2D outline. Make it either way:

- **Laser cut** it from **2 mm thick clear acrylic**, or
- **3D print** it: extrude the outline to **2 mm** and print it in a clear
  material.

### Hardware you'll need

| Qty | Part | Notes |
|---|---|---|
| 3 | M2.5 heat-set threaded inserts | Any height — there's plenty of clearance |
| 3 | M2.5 screws | Anything from 6 mm up to 12–16 mm long — there's plenty of room |
| 4 | 6 mm diameter stick-on rubber feet | Optional |

## Licence

Copyright (c) 2026 [Unexpected Maker](https://unexpectedmaker.com).

Licensed under the CERN Open Hardware Licence Version 2 — Strongly Reciprocal
(CERN-OHL-S v2). See [LICENSE](LICENSE).

If you distribute these files, a modified version of them, or anything made
from them, you must make the complete source available under the same licence.

Source location: <https://github.com/UnexpectedMaker/um_smart_usb_hub_6>

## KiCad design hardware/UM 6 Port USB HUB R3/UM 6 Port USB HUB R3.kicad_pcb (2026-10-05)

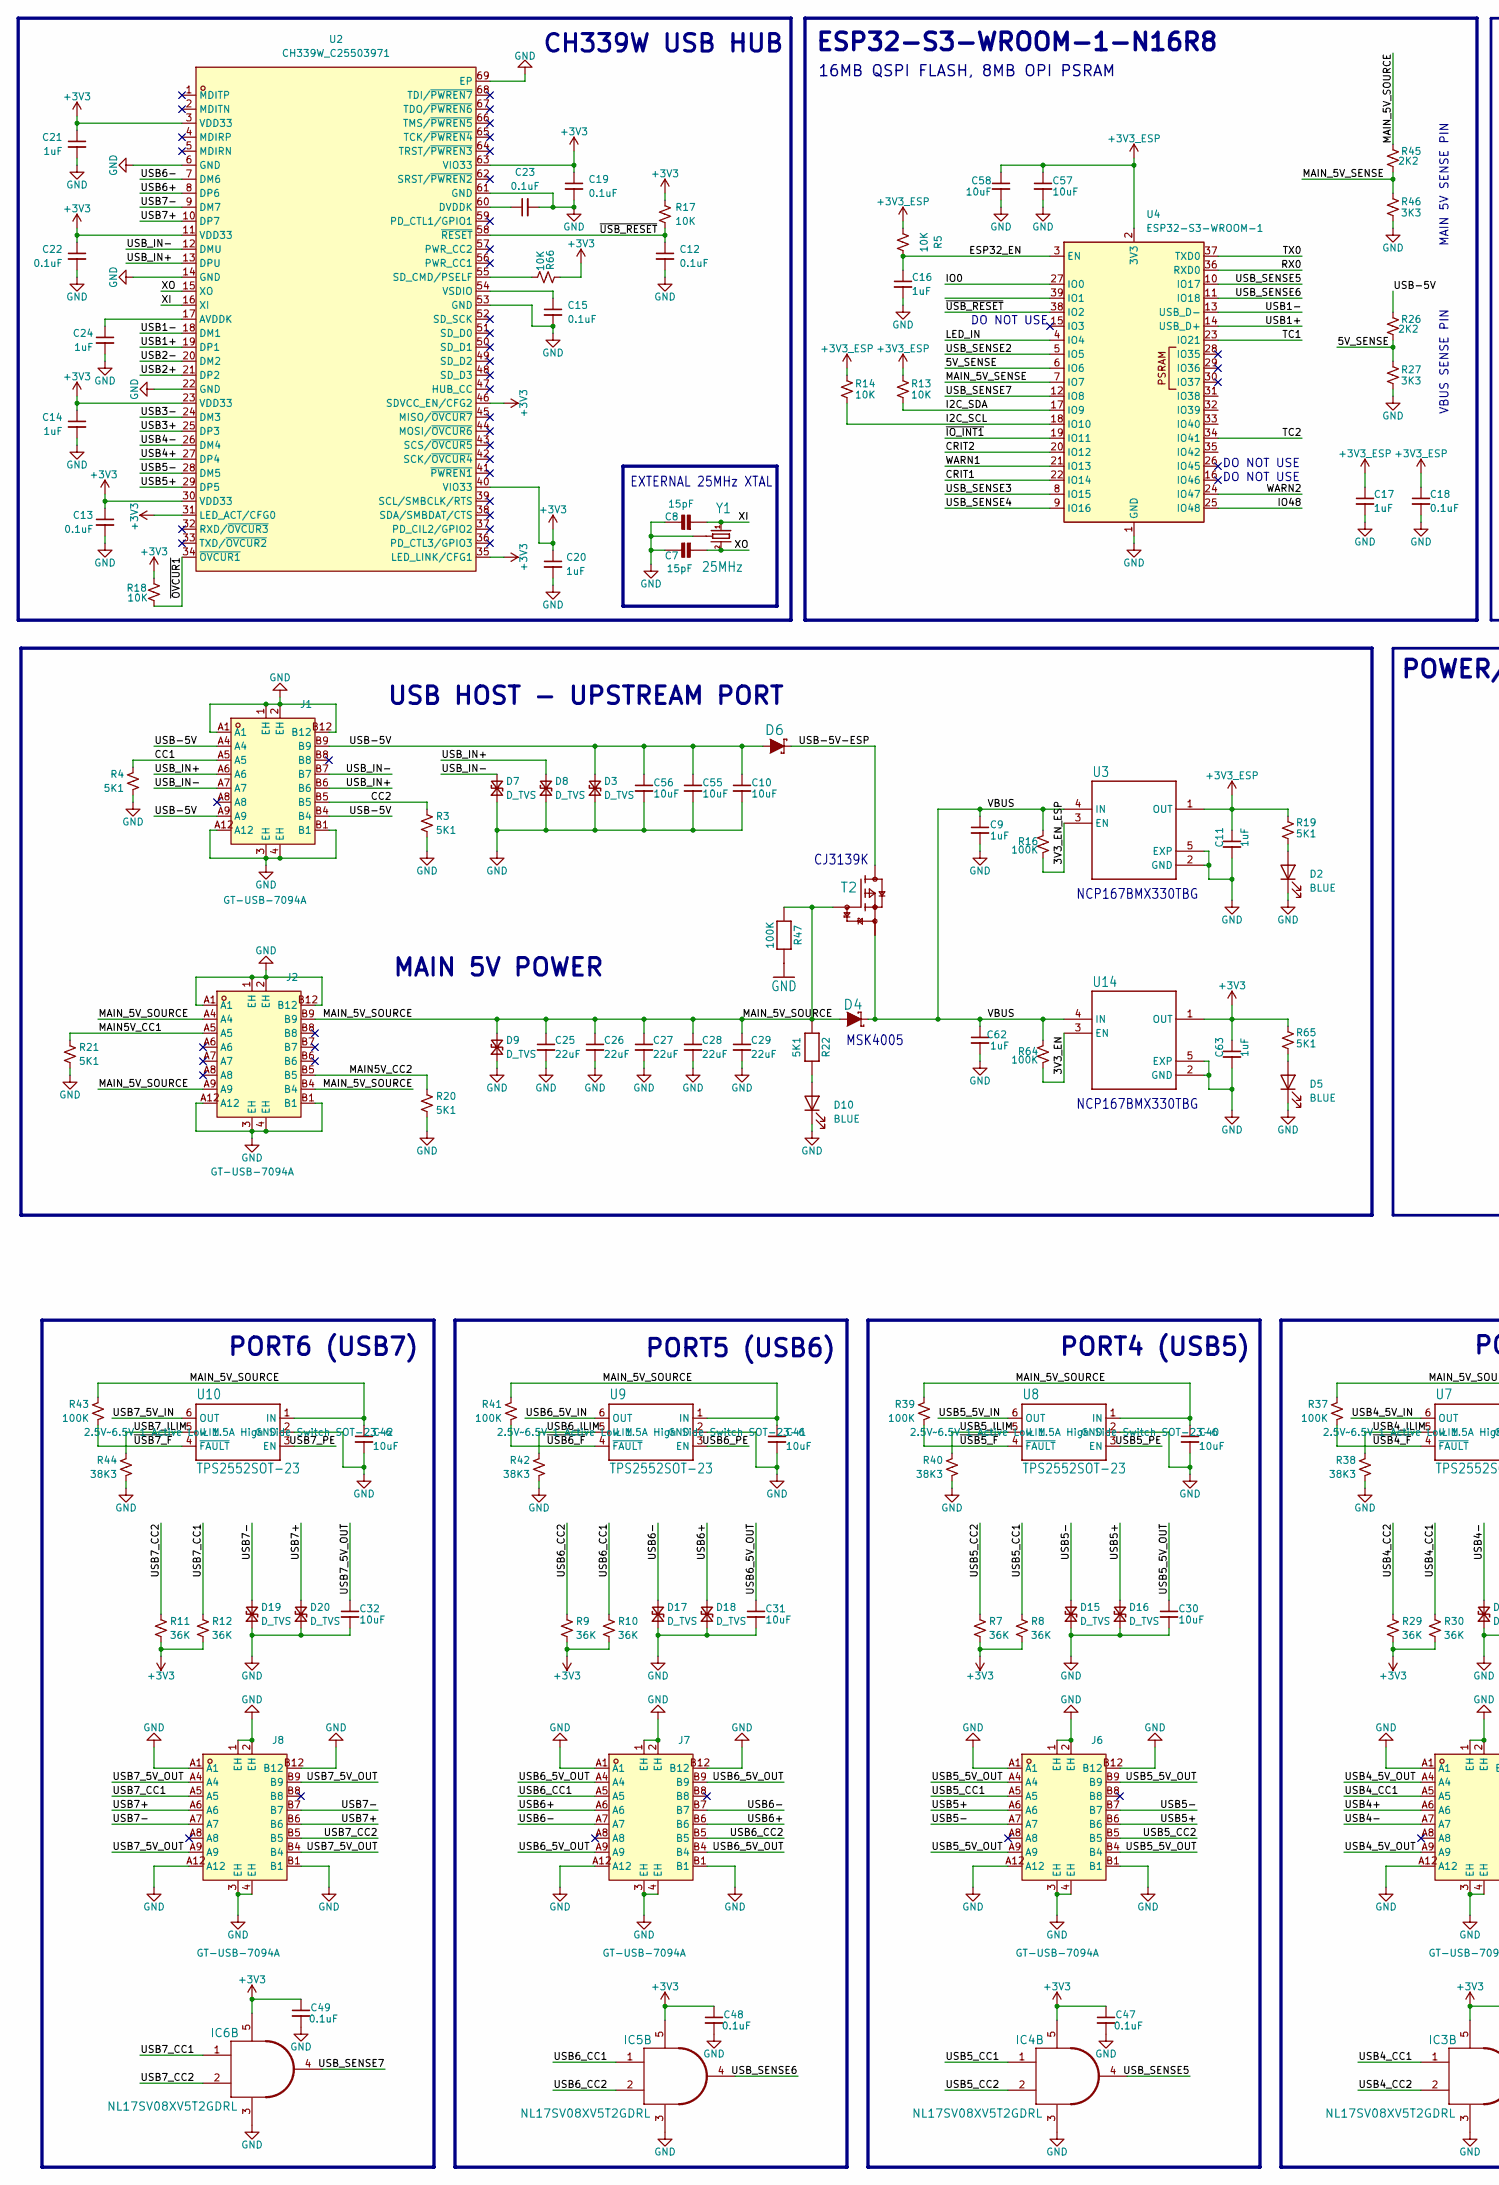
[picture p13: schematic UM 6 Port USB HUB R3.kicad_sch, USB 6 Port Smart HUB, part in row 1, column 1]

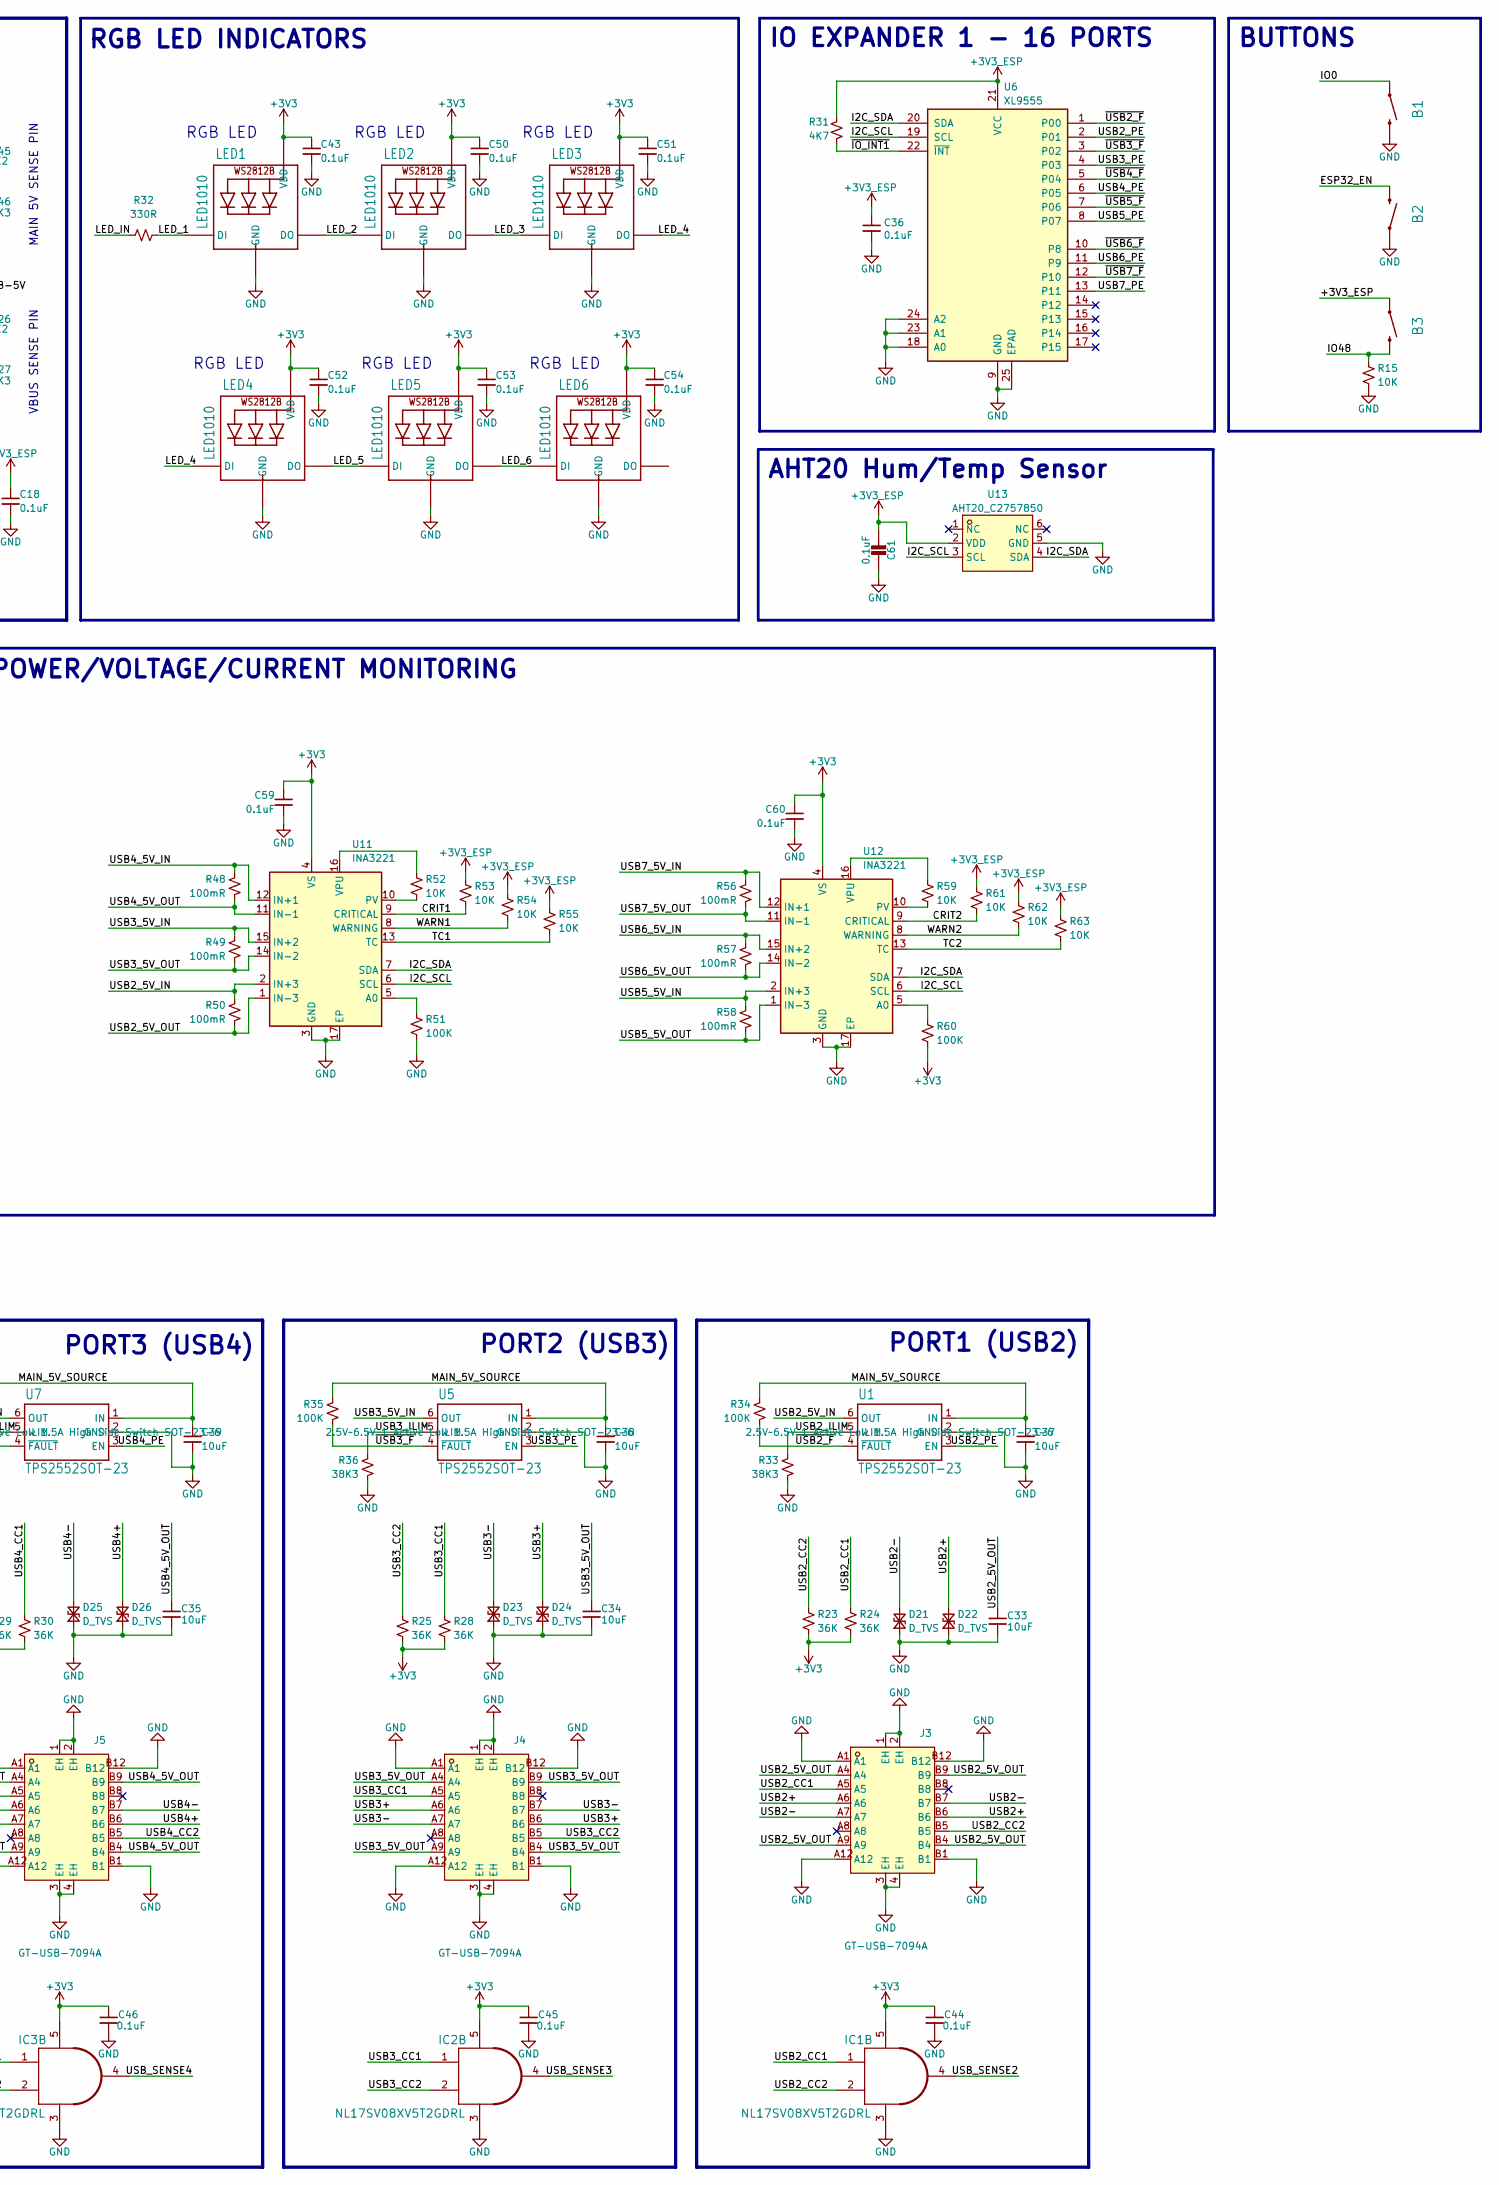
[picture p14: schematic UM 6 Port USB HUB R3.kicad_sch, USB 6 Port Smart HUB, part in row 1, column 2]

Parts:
B1, B2, B3: MOMENTARY-SWITCH-SPST-PTH-RIGHT-ANGLE-KIT; SMT_SWITCH_TS-1091C-A6B3-D2; MPN TS-1091C-A7B3-D2
C7, C8: 15pF; C_0402_NEW; MPN CC0402FRNPO9BN150
C9, C11, C14, C16, C17, C20, C21, C24, C62, C63: 1uF; C_0402_NEW; MPN CL05A105KA5NQNC
C10, C30, C31, C32, C33, C34, C35, C37, C38, C39, C40, C41, C42, C55, C56, C57, C58: 10uF; C_0603_NEW; MPN CGA0603X5R106K250JT
C12, C13, C15, C18, C19, C22, C23, C36, C43, C44, C45, C46, C47, C48, C49, C50, C51, C52, C53, C54, C59, C60, C61: 0.1uF; C_0402_NEW; MPN 0402B104K500CT
C25, C26, C27, C28, C29: 22uF; C_1210_3225Metric; MPN CC1210KKX5R8BB226
D2, D5, D10: BLUE; LED_0402_NEW; MPN TJ-S1005SW4TGLC6B-A5
D3, D7, D8, D9, D15, D16, D17, D18, D19, D20, D21, D22, D23, D24, D25, D26: D_TVS; TVS X1-DFN1006-2-BEST; MPN ESD05V88D-LC
D4, D6: DIODE-SCHOTTKYWIDE; SOD-523-MSK4010; MPN MSK4010
IC1, IC2, IC3, IC4, IC5, IC6: NL17SV08XV5T2GDRL; SOT553; MPN NL17SV08XV5T2GDRL
J1, J2, J3, J4, J5, J6, J7, J8: GT-USB-7094A; CONN-SMD_GT-USB-7094A; MPN GT-USB-7094A; LCSC Part C22383838
LED1, LED2, LED3, LED4, LED5, LED6: LED1010; MPN XL-1010RGBC-2812B
R3, R4, R19, R20, R21, R22, R65: 5K1; R_0402_NEW; MPN 0402WGF5101TCE
R5, R13, R14, R15, R17, R18, R52, R53, R54, R55, R59, R61, R62, R63, R66: 10K; R_0402_NEW; MPN 0402WGF1002TCE
R7, R8, R9, R10, R11, R12, R23, R24, R25, R28, R29, R30: 36K; R_0402_NEW; MPN RC0402FR-0736KL
R16, R34, R35, R37, R39, R41, R43, R47, R51, R60, R64: 100K; R_0402_NEW; MPN RC0402FR-07100KL
R26, R45: 2K2; R_0402_NEW; MPN RC0402FR-072K2L
R27, R46: 3K3; R_0402_NEW; MPN 0402WGF3301TCE
R31: 4K7; R_0402_NEW; MPN RT0402DRD074K7L
R32: 330R; R_0402_NEW; MPN RC0402FR-07442KL
R33, R36, R38, R40, R42, R44: 38K3; R_0402_NEW; MPN TC0225B3832TCC
R48, R49, R50, R56, R57, R58: 100mR; R_0805_NEW; MPN FBF05FTPR100
T2: P-FET; SOT723; MPN CJ3139K
U1, U5, U7, U8, U9, U10: TPS2552SOT-23; SOT-23-6; MPN TPS2552DBVR
U2: CH339W_C25503971; QFN-68_L8.0-W8.0-P0.40-BL-EP5.5; MPN CH339W; LCSC Part C25503971
U3, U14: NCP167BMX330TBG; VREG_NCP167BMX330TBG; MPN NCP167BMX330TBG
U4: ESP32-S3-WROOM-1; MPN ESP32-S3-WROOM-1
U6: XL9555; VQFN-24-1EP_4x4mm_P0.5mm_EP2.45x2.45mm; MPN XL9555QF24
U11, U12: INA3221; Texas_RGV0016A_VQFN-16-1EP_4x4mm_P0.65mm_EP2.1x2.1mm; MPN INA3221AIRGVR
U13: AHT20_C2757850; SENSOR-SMD_L3.0-W3.0-P1.00-BR; MPN AHT20; LCSC Part C2757850
Y1: 25MHz; CRYSTAL_2.5X2; MPN 2TJ425000UYFBC

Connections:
+3V3: C13.1, C14.1, C19.1, C20.1, C21.1, C22.1, C43.1, C44.1, C45.1, C46.1, C47.1, C48.1, C49.1, C50.1, C51.1, C52.1, C53.1, C54.1, C59.1, C60.1, C63.1, IC1.5 (PWR), IC2.5 (PWR), IC3.5 (PWR), IC4.5 (PWR), IC5.5 (PWR), IC6.5 (PWR), LED1.VDD, LED2.VDD, LED3.VDD, LED4.VDD, LED5.VDD, LED6.VDD, R7.2, R8.2, R9.2, R10.2, R11.2, R12.2, R17.1, R18.1, R23.2, R24.2, R25.2, R28.2, R29.2, R30.2, R60.2, R65.1, R66.1, U2.3 (VDD33), U2.11 (VDD33), U2.23 (VDD33), U2.30 (VDD33), U2.31 (LED_ACT/CFG0), U2.35 (LED_LINK/CFG1), U2.40 (VIO33), U2.46 (SDVCC_EN/CFG2), U2.63 (VIO33), U11.4 (VS), U12.4 (VS), U14.1 (OUT)
+3V3_ESP: B3.1, C11.1, C17.1, C18.1, C36.1, C57.1, C58.1, C61.2, R5.1, R13.1, R14.1, R19.1, R31.1, R53.1, R54.1, R55.1, R61.1, R62.1, R63.1, U3.1 (OUT), U4.2 (3V3), U6.21 (VCC), U13.2 (VDD)
/3V3_EN: R64.2, U14.3 (EN)
/3V3_EN_ESP: R16.2, U3.3 (EN)
/5V_SENSE: R26.1, R27.2, U4.6 (IO6)
/CC1: J1.A5, R4.1
/CC2: J1.B5, R3.1
/CRIT1: R53.2, U4.22 (IO14), U11.9 (CRITICAL)
/CRIT2: R61.2, U4.20 (IO12), U12.9 (CRITICAL)
/ESP32_EN: B2.2, C16.1, R5.2, U4.3 (EN)
/I2C_SCL: R14.2, U4.18 (IO10), U6.19 (SCL), U11.6 (SCL), U12.6 (SCL), U13.3 (SCL)
/I2C_SDA: R13.2, U4.17 (IO9), U6.20 (SDA), U11.7 (SDA), U12.7 (SDA), U13.4 (SDA)
/IO0: B1.1, U4.27 (IO0)
/IO48: B3.2, R15.1, U4.25 (IO48)
/LED_1: LED1.DIN (DI), R32.1
/LED_2: LED1.DOUT (DO), LED2.DIN (DI)
/LED_3: LED2.DOUT (DO), LED3.DIN (DI)
/LED_4: LED3.DOUT (DO), LED4.DIN (DI)
/LED_5: LED4.DOUT (DO), LED5.DIN (DI)
/LED_6: LED5.DOUT (DO), LED6.DIN (DI)
/LED_IN: R32.2, U4.4 (IO4)
/MAIN5V_CC1: J2.A5, R21.1
/MAIN5V_CC2: J2.B5, R20.1
/MAIN_5V_SENSE: R45.1, R46.2, U4.7 (IO7)
/MAIN_5V_SOURCE: C25.1, C26.1, C27.1, C28.1, C29.1, C37.1, C38.1, C39.1, C40.1, C41.1, C42.1, D4.A, D9.2 (A2), J2.A4, J2.A9, J2.B4, J2.B9, R22.1, R34.1, R35.1, R37.1, R39.1, R41.1, R43.1, R45.2, R47.1, T2.1 (G), U1.1 (IN), U5.1 (IN), U7.1 (IN), U8.1 (IN), U9.1 (IN), U10.1 (IN)
/RX0: U4.36 (RXD0)
/TC1: R55.2, U4.23 (IO21), U11.13 (TC)
/TC2: R63.2, U4.34 (IO41), U12.13 (TC)
/TX0: U4.37 (TXD0)
/USB1+: U2.19 (DP1), U4.14 (USB_D+)
/USB1-: U2.18 (DM1), U4.13 (USB_D-)
/USB2+: D22.2 (A2), J3.A6, J3.B6, U2.21 (DP2)
/USB2-: D21.2 (A2), J3.A7, J3.B7, U2.20 (DM2)
/USB2_5V_IN: R50.1, U1.6 (OUT), U11.2 (IN+3)
/USB2_5V_OUT: C33.1, J3.A4, J3.A9, J3.B4, J3.B9, R50.2, U11.1 (IN-3)
/USB2_CC1: IC1.1 (PWR), J3.A5, R24.1
/USB2_CC2: IC1.2 (I1), J3.B5, R23.1
/USB2_ILIM: R33.1, U1.5 (ILIM)
/USB2_PE: U1.3 (EN), U6.2 (P01)
/USB3+: D24.2 (A2), J4.A6, J4.B6, U2.25 (DP3)
/USB3-: D23.2 (A2), J4.A7, J4.B7, U2.24 (DM3)
/USB3_5V_IN: R49.1, U5.6 (OUT), U11.15 (IN+2)
/USB3_5V_OUT: C34.1, J4.A4, J4.A9, J4.B4, J4.B9, R49.2, U11.14 (IN-2)
/USB3_CC1: IC2.1 (PWR), J4.A5, R28.1
/USB3_CC2: IC2.2 (I1), J4.B5, R25.1
/USB3_ILIM: R36.1, U5.5 (ILIM)
/USB3_PE: U5.3 (EN), U6.4 (P03)
/USB4+: D26.2 (A2), J5.A6, J5.B6, U2.27 (DP4)
/USB4-: D25.2 (A2), J5.A7, J5.B7, U2.26 (DM4)
/USB4_5V_IN: R48.1, U7.6 (OUT), U11.12 (IN+1)
/USB4_5V_OUT: C35.1, J5.A4, J5.A9, J5.B4, J5.B9, R48.2, U11.11 (IN-1)
/USB4_CC1: IC3.1 (PWR), J5.A5, R30.1
/USB4_CC2: IC3.2 (I1), J5.B5, R29.1
/USB4_ILIM: R38.1, U7.5 (ILIM)
/USB4_PE: U6.6 (P05), U7.3 (EN)
/USB5+: D16.2 (A2), J6.A6, J6.B6, U2.29 (DP5)
/USB5-: D15.2 (A2), J6.A7, J6.B7, U2.28 (DM5)
/USB5_5V_IN: R58.1, U8.6 (OUT), U12.2 (IN+3)
/USB5_5V_OUT: C30.1, J6.A4, J6.A9, J6.B4, J6.B9, R58.2, U12.1 (IN-3)
/USB5_CC1: IC4.1 (PWR), J6.A5, R8.1
/USB5_CC2: IC4.2 (I1), J6.B5, R7.1
/USB5_ILIM: R40.1, U8.5 (ILIM)
/USB5_PE: U6.8 (P07), U8.3 (EN)
/USB6+: D18.2 (A2), J7.A6, J7.B6, U2.8 (DP6)
/USB6-: D17.2 (A2), J7.A7, J7.B7, U2.7 (DM6)
/USB6_5V_IN: R57.1, U9.6 (OUT), U12.15 (IN+2)
/USB6_5V_OUT: C31.1, J7.A4, J7.A9, J7.B4, J7.B9, R57.2, U12.14 (IN-2)
/USB6_CC1: IC5.1 (PWR), J7.A5, R10.1
/USB6_CC2: IC5.2 (I1), J7.B5, R9.1
/USB6_ILIM: R42.1, U9.5 (ILIM)
/USB6_PE: U6.11 (P9), U9.3 (EN)
/USB7+: D20.2 (A2), J8.A6, J8.B6, U2.10 (DP7)
/USB7-: D19.2 (A2), J8.A7, J8.B7, U2.9 (DM7)
/USB7_5V_IN: R56.1, U10.6 (OUT), U12.12 (IN+1)
/USB7_5V_OUT: C32.1, J8.A4, J8.A9, J8.B4, J8.B9, R56.2, U12.11 (IN-1)
/USB7_CC1: IC6.1 (PWR), J8.A5, R12.1
/USB7_CC2: IC6.2 (I1), J8.B5, R11.1
/USB7_ILIM: R44.1, U10.5 (ILIM)
/USB7_PE: U6.13 (P11), U10.3 (EN)
/USB-5V: C10.1, C55.1, C56.1, D3.2 (A2), D6.A, J1.A4, J1.A9, J1.B4, J1.B9, R26.2
/USB-5V-ESP: D6.C, T2.3 (D)
/USB_IN+: D8.2 (A2), J1.A6, J1.B6, U2.13 (DPU)
/USB_IN-: D7.2 (A2), J1.A7, J1.B7, U2.12 (DMU)
/USB_SENSE2: IC1.4 (O), U4.5 (IO5)
/USB_SENSE3: IC2.4 (O), U4.8 (IO15)
/USB_SENSE4: IC3.4 (O), U4.9 (IO16)
/USB_SENSE5: IC4.4 (O), U4.10 (IO17)
/USB_SENSE6: IC5.4 (O), U4.11 (IO18)
/USB_SENSE7: IC6.4 (O), U4.12 (IO8)
/VBUS: C9.1, C62.1, D4.C, R16.1, R64.1, T2.2 (S), U3.4 (IN), U14.4 (IN)
/WARN1: R54.2, U4.21 (IO13), U11.8 (WARNING)
/WARN2: R62.2, U4.24 (IO47), U12.8 (WARNING)
/XI: C8.2, U2.16 (XI), Y1.1
/XO: C7.2, U2.15 (XO), Y1.3 (2)
/~IO_INT1: R31.2, U4.19 (IO11), U6.22 (~INT)
/~OVCUR1: R18.2, U2.34 (~OVCUR1)
/~USB2_F: R34.2, U1.4 (~FAULT), U6.1 (P00)
/~USB3_F: R35.2, U5.4 (~FAULT), U6.3 (P02)
/~USB4_F: R37.2, U6.5 (P04), U7.4 (~FAULT)
/~USB5_F: R39.2, U6.7 (P06), U8.4 (~FAULT)
/~USB6_F: R41.2, U6.10 (P8), U9.4 (~FAULT)
/~USB7_F: R43.2, U6.12 (P10), U10.4 (~FAULT)
/~USB_RESET: C12.1, R17.2, U2.58 (~RESET), U4.38 (IO2)
GND: B1.2, B2.1, C7.1, C8.1, C9.2, C10.2, C11.2, C12.2, C13.2, C14.2, C15.2, C16.2, C17.2, C18.2, C19.2, C20.2, C21.2, C22.2, C23.2, C24.2, C25.2, C26.2, C27.2, C28.2, C29.2, C30.2, C31.2, C32.2, C33.2, C34.2, C35.2, C36.2, C37.2, C38.2, C39.2, C40.2, C41.2, C42.2, C43.2, C44.2, C45.2, C46.2, C47.2, C48.2, C49.2, C50.2, C51.2, C52.2, C53.2, C54.2, C55.2, C56.2, C57.2, C58.2, C59.2, C60.2, C61.1, C62.2, C63.2, D2.1 (K), D3.1 (A1), D5.1 (K), D7.1 (A1), D8.1 (A1), D9.1 (A1), D10.1 (K), D15.1 (A1), D16.1 (A1), D17.1 (A1), D18.1 (A1), D19.1 (A1), D20.1 (A1), D21.1 (A1), D22.1 (A1), D23.1 (A1), D24.1 (A1), D25.1 (A1), D26.1 (A1), IC1.3 (GND), IC2.3 (GND), IC3.3 (GND), IC4.3 (GND), IC5.3 (GND), IC6.3 (GND), J1.1 (EH), J1.2 (EH), J1.3 (EH), J1.4 (EH), J1.A1, J1.A12, J1.B1, J1.B12, J2.1 (EH), J2.2 (EH), J2.3 (EH), J2.4 (EH), J2.A1, J2.A12, J2.B1, J2.B12, J3.1 (EH), J3.2 (EH), J3.3 (EH), J3.4 (EH), J3.A1, J3.A12, J3.B1, J3.B12, J4.1 (EH), J4.2 (EH), J4.3 (EH), J4.4 (EH), J4.A1, J4.A12, J4.B1, J4.B12, J5.1 (EH), J5.2 (EH), J5.3 (EH), J5.4 (EH), J5.A1, J5.A12, J5.B1, J5.B12, J6.1 (EH), J6.2 (EH), J6.3 (EH), J6.4 (EH), J6.A1, J6.A12, J6.B1, J6.B12, J7.1 (EH), J7.2 (EH), J7.3 (EH), J7.4 (EH), J7.A1, J7.A12, J7.B1, J7.B12, J8.1 (EH), J8.2 (EH), J8.3 (EH), J8.4 (EH), J8.A1, J8.A12, J8.B1, J8.B12, LED1.GND, LED2.GND, LED3.GND, LED4.GND, LED5.GND, LED6.GND, R3.2, R4.2, R15.2, R20.2, R21.2, R27.1, R33.2, R36.2, R38.2, R40.2, R42.2, R44.2, R46.1, R47.2, R51.2, U1.2 (GND), U2.6 (GND), U2.14 (GND), U2.22 (GND), U2.53 (GND), U2.61 (GND), U2.69 (EP), U3.2 (GND), U3.5 (EXP), U4.1 (GND), U4.40 (GND), U4.41 (GND), U5.2 (GND), U6.9 (GND), U6.18 (A0), U6.23 (A1), U6.24 (A2), U6.25 (EPAD), U7.2 (GND), U8.2 (GND), U9.2 (GND), U10.2 (GND), U11.3 (GND), U11.17 (EP), U12.3 (GND), U12.17 (EP), U13.5 (GND), U14.2 (GND), U14.5 (EXP), Y1.2 (GND), Y1.4 (GND)
unnamed: D2.2 (A), R19.2
unnamed: D5.2 (A), R65.2
unnamed: D10.2 (A), R22.2
unnamed: C24.1, U2.17 (AVDDK)
unnamed: C23.1, U2.60 (DVDDK)
unnamed: R66.2, U2.55 (SD_CMD/PSELF)
unnamed: C15.1, U2.54 (VSDIO)
unnamed: R51.1, U11.5 (A0)
unnamed: R52.2, U11.10 (PV)
unnamed: R52.1, U11.16 (VPU)
unnamed: R60.1, U12.5 (A0)
unnamed: R59.2, U12.10 (PV)
unnamed: R59.1, U12.16 (VPU)

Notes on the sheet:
PORT4 (USB5)
DO NOT USE
RGB LED
AHT20 Hum/Temp Sensor
PORT1 (USB2)
MAIN 5V POWER
ESP32-S3-WROOM-1-N16R8
16MB QSPI FLASH, 8MB OPI PSRAM
RGB LED INDICATORS
PORT6 (USB7)
USB HOST - UPSTREAM PORT
PORT3 (USB4)
CH339W USB HUB
VBUS SENSE PIN
PORT5 (USB6)
BUTTONS
NCP167BMX330TBG
POWER/VOLTAGE/CURRENT MONITORING
CJ3139K
MSK4005
MAIN 5V SENSE PIN
EXTERNAL 25MHz XTAL
IO EXPANDER 1 - 16 PORTS
PORT2 (USB3)

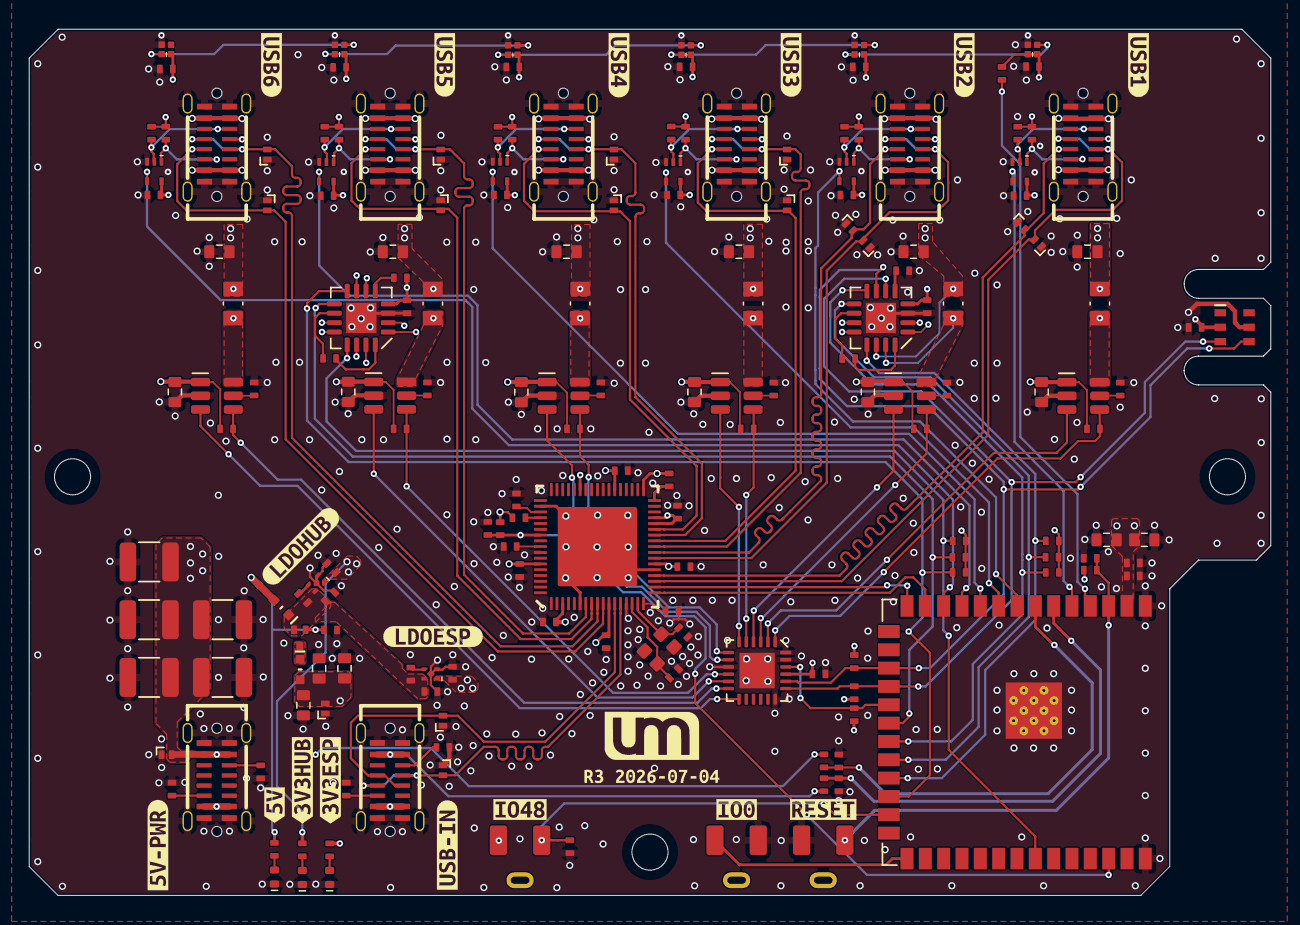
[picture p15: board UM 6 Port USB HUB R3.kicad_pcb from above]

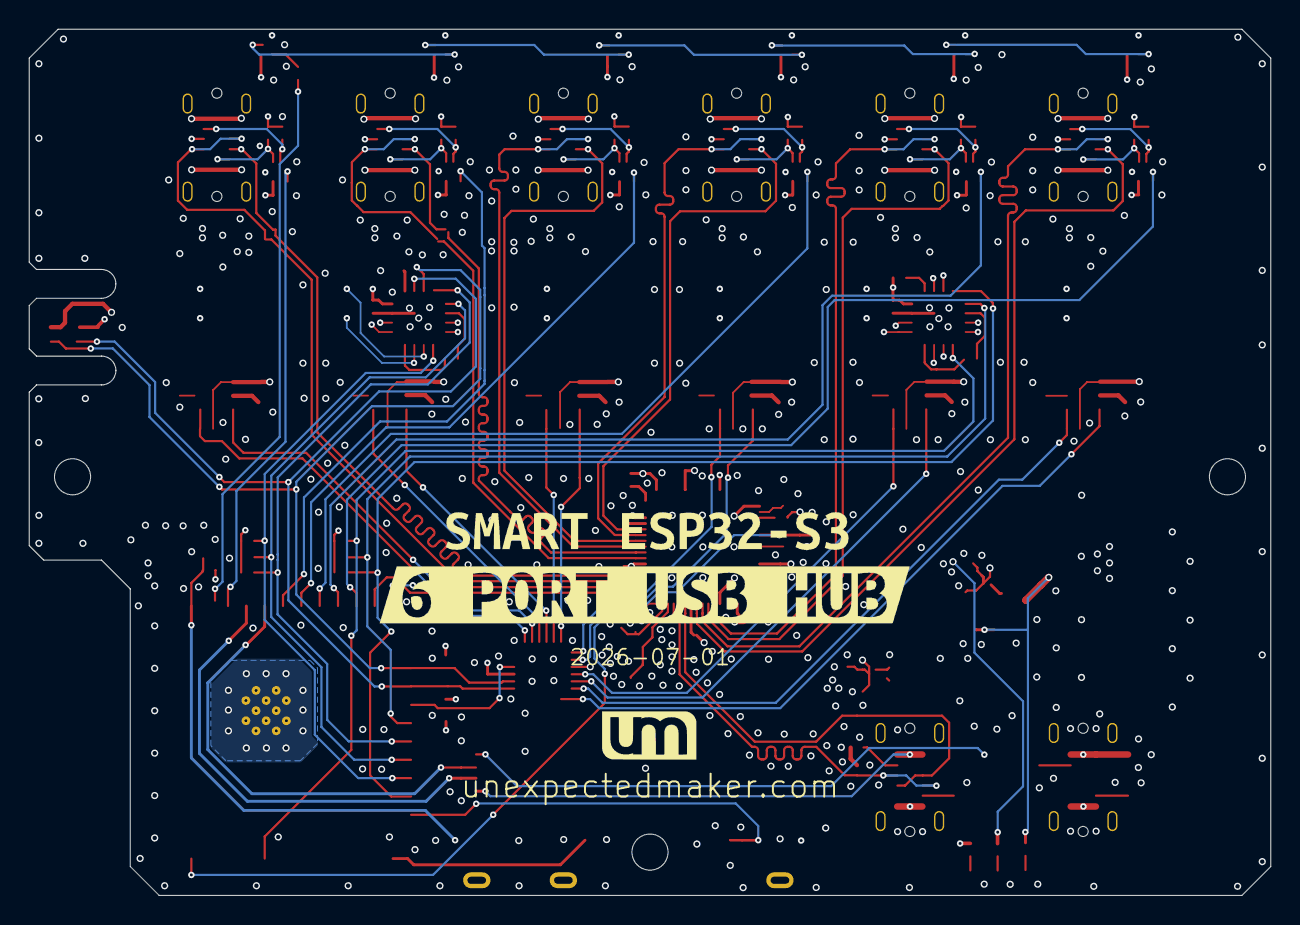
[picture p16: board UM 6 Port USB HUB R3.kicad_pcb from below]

Board: 4 copper layers, 86.0 x 60.0 mm, 200 parts (3 on the bottom side), 115 nets.

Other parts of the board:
U$2: UM_LOGONEW_SMALL; UM_LOGO_NEW_SMALL
kibuzzard-6A0CC55D: G***; kibuzzard-6A0CC55D
kibuzzard-6A0CC533: G***; kibuzzard-6A0CC533
kibuzzard-6A160FA6: G***; kibuzzard-6A160FA6
kibuzzard-6A160FAE: G***; kibuzzard-6A160FAE
kibuzzard-6A160FB8: G***; kibuzzard-6A160FB8
kibuzzard-6A160FBE: G***; kibuzzard-6A160FBE
kibuzzard-6A160FC5: G***; kibuzzard-6A160FC5
kibuzzard-6A447CB2: G***; kibuzzard-6A447CB2
kibuzzard-6A472ABE: G***; kibuzzard-6A472ABE
kibuzzard-6A1603D6: G***; kibuzzard-6A1603D6
kibuzzard-6A4480B2: G***; kibuzzard-6A4480B2
kibuzzard-6A4480C0: G***; kibuzzard-6A4480C0
kibuzzard-6A48901C: G***; kibuzzard-6A48901C
kibuzzard-6A48903D: G***; kibuzzard-6A48903D
kibuzzard-6A48904C: G***; kibuzzard-6A48904C
kibuzzard-6A48947B: G***; kibuzzard-6A48947B
kibuzzard-6A160306: G***; kibuzzard-6A160306
kibuzzard-6A160323: G***; kibuzzard-6A160323
kibuzzard-6A489058: G***; kibuzzard-6A489058

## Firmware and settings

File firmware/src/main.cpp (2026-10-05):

// SPDX-License-Identifier: GPL-3.0-or-later
// Copyright (c) 2026 Unexpected Maker
//
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
// main.cpp — Smart USB Hub firmware (ESP32-S3).
//
// Six USB-C downstream ports behind a WCH CH339W hub. For each port the ESP32
// can switch its 5V (TPS2552 load switch, via an XL9555 I/O expander), see an
// over-current fault, see a device plugged in even with the power off, and
// measure voltage / current / power (two INA3221s). Each port has an RGB LED
// showing its state.
//
// This file holds the application:
//   - pin map and hardware objects
//   - port LEDs (boot sweep, then live per-port state)
//   - power scheduler (weekly schedules, catch-up after a reboot)
//   - JSON for the web UI and the REST API
//   - WiFi, OTA and mDNS
//   - serial console (type 'help')
//   - setup() and loop()
//
// The rest of the firmware:
//   ports/      USBPort — one port's power, fault and device sense
//   settings/   HubSettings — everything stored in flash
//   web/        HubWebServer (routes, API) and HubWebUI (the embedded page)
//   ../lib/     the INA3221 and XL9555 drivers, and the JSON library
#include <Arduino.h>
#include <Wire.h>
#include <WiFi.h>
#include <ArduinoOTA.h>
#include <ESPmDNS.h>
#include <esp_system.h>
#include <time.h>
#include <vector>
#include <algorithm>
#include <Adafruit_NeoPixel.h>
#include <DHT20.h>
#include "UM_LCA9555.h"
#include "UM_INA3221.h"
#include "ports/USBPort.h"
#include "web/HubWebServer.h"
#include "settings/HubSettings.h"

// Firmware version, reported by the web UI, the API and 'info'.
#define HUB_FW_VERSION "1.0.0"

#define NUM_PORTS HUB_NUM_PORTS

// ===========================================================================
// Pin map (ESP32-S3)
// ===========================================================================

// Shared I2C bus: I/O expander (0x20), INA3221 x2 (0x40, 0x41), AHT20 (0x38).
#define I2C_SDA 9
#define I2C_SCL 10
#define EXP_INT_PIN 11 // I/O expander INT, active LOW, open-drain
#define BUTTON_PIN 48  // user button, external pull-down, pressed = HIGH
#define LED_PIN 4      // WS2812B data, one LED per port

// INA3221 alert outputs: open-drain with external pull-ups, so they idle HIGH
// and pull LOW when asserted. Only read (by 'mon'); faults come from the load
// switches, not from these.
#define INA1_TC_PIN 21 // INA3221 #1, ports 1-3
#define INA1_CRIT_PIN 14
#define INA1_WARN_PIN 13
#define INA2_TC_PIN 41 // INA3221 #2, ports 4-6
#define INA2_CRIT_PIN 12
#define INA2_WARN_PIN 47

// Hub IC reset, active LOW. Wired, but not used by the firmware.
#define USB_RESET_PIN 2

// 5V present-sense lines. HIGH = present.
#define MAIN_5V_SENSE_PIN 7     // the separate 5V input that powers the ports
#define UPSTREAM_5V_SENSE_PIN 6 // the upstream (host) USB connector

// ===========================================================================
// Hardware objects and global state
// ===========================================================================

Adafruit_NeoPixel strip(NUM_PORTS, LED_PIN, NEO_GRB + NEO_KHZ800);

// Persists every settings group to /settings.json.
HubConfig config;

// Power monitors. Measurement only — over-current faults come from the
// TPS2552 load switches. Channels run high-to-low: CH1 is the chip's highest
// port. Every channel has a 100 mOhm shunt.
INA3221 ina_a; // 0x40, ports 1-3
INA3221 ina_b; // 0x41, ports 4-6
#define INA_SHUNT_OHMS 0.1f

// Temperature / humidity. The AHT20 is register-compatible with the DHT20.
DHT20 aht;
float g_tempC = 0.0f, g_humid = 0.0f;
bool g_tempValid = false; // true after the first good read

// Which optional chips answered at boot. Missing ones are reported as
// unavailable rather than polled.
bool g_ahtOk = false;
bool g_inaAok = false;
bool g_inaBok = false;

// The six downstream ports:  index, sense GPIO, expander enable pin, expander
// fault pin.
USBPort ports[NUM_PORTS] = {
    USBPort(0, 5, 1, 0),
    USBPort(1, 15, 3, 2),
    USBPort(2, 16, 5, 4),
    USBPort(3, 17, 7, 6),
    USBPort(4, 18, 9, 8),
    USBPort(5, 8, 11, 10),
};

static const char *DOW_NAME[] = {"Sun", "Mon", "Tue", "Wed", "Thu", "Fri", "Sat"};

// ===========================================================================
// Port hardware helpers
// ===========================================================================

// Set by the expander interrupt; handled in loop(). Starts true so the first
// pass reads the current fault state. The ISR only sets the flag — the I2C
// read that clears the interrupt happens in serviceExpander().
volatile bool g_expanderIrq = true;

void IRAM_ATTR onExpanderInt() { g_expanderIrq = true; }

// A fault line changed somewhere: read both expander input registers once and
// let every port pick out its own fault bit.
void serviceExpander()
{
    uint8_t reg0 = ioex.read_port(0);
    uint8_t reg1 = ioex.read_port(1);
    for (auto &port : ports)
        port.applyFault(reg0, reg1);
}

bool main5vPresent() { return digitalRead(MAIN_5V_SENSE_PIN) == HIGH; }
bool upstream5vPresent() { return digitalRead(UPSTREAM_5V_SENSE_PIN) == HIGH; }

// One port's measurements. ok = false when that port's INA3221 isn't fitted.
struct PortReading
{
    bool ok;
    float volts, ma, mw;
};

// Read port i (0-based). Ports 1-3 are on ina_a, 4-6 on ina_b, and each chip
// numbers its channels high-to-low (port 1 = CH3 .. port 3 = CH1).
PortReading readPort(uint8_t i)
{
    INA3221 &chip = (i < 3) ? ina_a : ina_b;
    bool present = (i < 3) ? g_inaAok : g_inaBok;
    uint8_t ch = 3 - (i % 3);
    if (!present)
        return {false, 0.0f, 0.0f, 0.0f};
    return {true, chip.bus_voltage_V(ch), chip.current_mA(ch), chip.power_mW(ch)};
}

// Total current and power across all monitored ports.
void totalDraw(float &ma, float &mw)
{
    ma = mw = 0.0f;
    for (uint8_t i = 0; i < NUM_PORTS; i++)
    {
        PortReading r = readPort(i);
        ma += r.ma;
        mw += r.mw;
    }
}

// The port's LED state as a short name — the same decision renderLeds() makes.
// Sent to the web UI so it can show exactly what the LED shows.
const char *portStateStr(USBPort &p)
{
    if (p.isEnabled())
    {
        if (p.hasFault())
            return "fault";
        if (!main5vPresent())
            return p.isOccupied() ? "pink" : "pinkpulse";
        return p.isOccupied() ? "green" : "pulse";
    }
    return p.isOccupied() ? "blue" : "off";
}

// ===========================================================================
// Port LEDs
// ===========================================================================

// Boot sweep: one pass across all six LEDs as soon as settings are loaded —
// green if an SSID is stored, red if not. Nothing waits for it; the port
// states take over the moment it ends.
#define BOOT_SWEEP_MS 700
static uint32_t g_bootSweepAt = 0; // millis() when it started; 0 = not running
static bool g_bootSweepRed = false;

void startBootSweep(bool red)
{
    g_bootSweepRed = red;
    g_bootSweepAt = millis() | 1; // never 0, which means "not running"
    Serial.printf("[led] %lu ms  boot sweep %s\n", (unsigned long)millis(),
                  red ? "RED (no SSID)" : "GREEN (SSID set)");
}

// Draw one frame of the boot sweep. Returns false once it's over.
bool renderBootSweep()
{
    if (!g_bootSweepAt)
        return false;
    uint32_t now = millis();
    uint32_t t = now - g_bootSweepAt;
    if (t >= BOOT_SWEEP_MS)
    {
        g_bootSweepAt = 0;
        Serial.printf("[led] %lu ms  boot sweep done\n", (unsigned long)now);
        return false;
    }
    // The head moves one LED every 100 ms, leaving a short fading trail.
    int head = (int)(t / 100);
    for (uint8_t i = 0; i < NUM_PORTS; i++)
    {
        int d = head - i;
        uint8_t v = (d == 0) ? 255 : (d == 1 ? 90 : (d > 1 ? 25 : 0));
        strip.setPixelColor(i, g_bootSweepRed ? strip.Color(v, 0, 0) : strip.Color(0, v, 0));
    }
    strip.show();
    return true;
}

// 2 s sine pulse from 10% to 100%, shared by every pulsing state so all ports
// stay in step (the web UI mirrors this exact shape).
static float pulseLevel(uint32_t now)
{
    float ph = (now % 2000) / 2000.0f;
    float f = (sinf(ph * 2.0f * PI - PI / 2.0f) + 1.0f) * 0.5f;
    return 0.1f + 0.9f * f;
}

// Draw every port's LED from its live state. Runs every frame because the
// pulse and flash effects are time based.
//
//   powered, over-current         flashing red (250 ms on / off)
//   powered, no main 5V, device   solid pink
//   powered, no main 5V, empty    pulsing pink
//   powered, device               solid green
//   powered, empty                pulsing blue
//   unpowered, device             solid blue
//   unpowered, empty              off
void renderLeds()
{
    // LEDs switched off in settings: blank once, then leave them alone.
    static bool wasCleared = false;
    static int lastBrightness = -1;
    if (!g_leds.config().enabled)
    {
        if (!wasCleared)
        {
            strip.clear();
            strip.show();
            wasCleared = true;
        }
        return;
    }
    wasCleared = false;
    if ((int)g_leds.config().brightness != lastBrightness)
    {
        lastBrightness = g_leds.config().brightness;
        strip.setBrightness((uint8_t)lastBrightness);
    }

    uint32_t now = millis();
    for (uint8_t i = 0; i < NUM_PORTS; i++)
    {
        USBPort &port = ports[i];
        uint8_t r = 0, g = 0, b = 0;
        if (port.isEnabled())
        {
            if (port.hasFault())
            {
                if ((now / 250) % 2 == 0)
                    r = 255;
            }
            else if (!main5vPresent())
            {
                float amp = port.isOccupied() ? 1.0f : pulseLevel(now);
                r = (uint8_t)(255 * amp);
                g = (uint8_t)(90 * amp);
                b = (uint8_t)(200 * amp);
            }
            else if (port.isOccupied())
                g = 255;
            else
                b = (uint8_t)(255 * pulseLevel(now));
        }
        else if (port.isOccupied())
            b = 255;
        strip.setPixelColor(i, strip.Color(r, g, b));
    }
    strip.show();
}

// ===========================================================================
// Clock
// ===========================================================================

// True once NTP has set the clock (anything after 2023-01-01).
bool timeSynced() { return time(nullptr) > 1672531200; }

// Current local time (the timezone comes from the location settings). False
// until the clock is synced.
bool localNow(struct tm &out)
{
    if (!timeSynced())
        return false;
    time_t t = time(nullptr);
    localtime_r(&t, &out);
    return true;
}

// Minutes since Sunday 00:00 — the scheduler's time axis (0..10079).
int weekMinute(const struct tm &t) { return t.tm_wday * 1440 + t.tm_hour * 60 + t.tm_min; }

// Why the previous boot ended, as a short word.
const char *resetReasonStr(esp_reset_reason_t r)
{
    switch (r)
    {
    case ESP_RST_POWERON:   return "POWERON";
    case ESP_RST_EXT:       return "EXT";
    case ESP_RST_SW:        return "SW";
    case ESP_RST_PANIC:     return "PANIC";
    case ESP_RST_INT_WDT:   return "INT_WDT";
    case ESP_RST_TASK_WDT:  return "TASK_WDT";
    case ESP_RST_WDT:       return "WDT";
    case ESP_RST_DEEPSLEEP: return "DEEPSLEEP";
    case ESP_RST_BROWNOUT:  return "BROWNOUT";
    case ESP_RST_SDIO:      return "SDIO";
    case ESP_RST_USB:       return "USB";        // reset over USB, e.g. flashing
    case ESP_RST_JTAG:      return "JTAG";
    case ESP_RST_EFUSE:     return "EFUSE";
    case ESP_RST_PWR_GLITCH: return "PWR_GLITCH";
    case ESP_RST_CPU_LOCKUP: return "CPU_LOCKUP";
    default:                return "UNKNOWN";
    }
}

// ===========================================================================
// Power scheduler
//
// Every schedule entry is expanded into switch events on a one-week axis
// (minutes from Sunday 00:00). A port's state at any moment is whatever its
// most recent event said. That one rule covers every mode, makes overlapping
// entries resolve predictably, and lets a reboot work out the correct state.
// ===========================================================================

struct SchedEvent
{
    int at;    // minutes from Sunday 00:00
    bool on;   // switch on or off
    int idx;   // the schedule entry that produced it
    bool tail; // true for the automatic OFF that ends an entry's window
};

// Expand one port's valid, enabled entries into a sorted list of events.
void buildEvents(uint8_t port, std::vector<SchedEvent> &out)
{
    out.clear();
    const auto &list = g_schedules.config().ports[port];
    for (size_t k = 0; k < list.size(); k++)
    {
        const auto &e = list[k];
        if (e.invalid || !e.enabled)
            continue;
        int t = hubParseHHMM(e.time);
        if (t < 0 || e.days == 0)
            continue;

        // ON EVERY: a pulse every `every` minutes, all day or across a window.
        if (e.on && e.mode == 3)
        {
            int iv = max((int)e.every, SCHED_MIN_EVERY);
            int pulse = e.dur > 0 ? e.dur : 1;
            if (pulse >= iv)
                continue; // flagged by validate()
            int from = 0, span = 1440;
            if (!e.allday)
            {
                int u = hubParseHHMM(e.until);
                if (u < 0)
                    continue;
                from = t;
                span = (u - t + 1440) % 1440; // may wrap past midnight
                if (span == 0)
                    continue; // flagged by validate()
            }
            for (int d = 0; d < 7; d++)
            {
                if (!((e.days >> d) & 1))
                    continue;
                for (int off = 0; off < span; off += iv)
                {
                    int at = (d * 1440 + from + off) % 10080;
                    out.push_back({at, true, (int)k, false});
                    out.push_back({(at + pulse) % 10080, false, (int)k, true});
                }
            }
            continue;
        }

        // OFF / ON / ON FOR / ON UNTIL: one event per day, plus the closing
        // OFF for entries with a window.
        int win = hubEntryWindow(e);
        for (int d = 0; d < 7; d++)
        {
            if (!((e.days >> d) & 1))
                continue;
            out.push_back({d * 1440 + t, e.on, (int)k, false});
            if (e.on && win > 0)
                out.push_back({(d * 1440 + t + win) % 10080, false, (int)k, true});
        }
    }
    // Time order; at the same instant ON comes before OFF.
    std::sort(out.begin(), out.end(), [](const SchedEvent &a, const SchedEvent &b) {
        return (a.at != b.at) ? a.at < b.at : a.on > b.on;
    });
}

// Expanded events per port. ON EVERY entries expand into hundreds of events,
// so these are rebuilt only when the schedules change. Only the main loop
// touches them; web requests read the precomputed g_next instead.
static std::vector<SchedEvent> g_evCache[NUM_PORTS];
static uint32_t g_evCacheVer = 0xFFFFFFFFu;

void refreshEventCache()
{
    uint32_t v = g_schedules.version();
    if (v == g_evCacheVer)
        return;
    for (uint8_t i = 0; i < NUM_PORTS; i++)
    {
        buildEvents(i, g_evCache[i]);
        g_evCache[i].shrink_to_fit();
    }
    g_evCacheVer = v;
}

// Each port's next event, worked out on the main loop so answering a web
// request needs no allocation.
struct NextInfo
{
    int at = -1; // minutes from Sunday 00:00; -1 = nothing scheduled
    bool on = false;
    int idx = -1; // the schedule entry that produced it
};
static NextInfo g_next[NUM_PORTS];

void refreshNextInfo(int nowAt)
{
    for (uint8_t i = 0; i < NUM_PORTS; i++)
    {
        const auto &ev = g_evCache[i];
        NextInfo n;
        if (!ev.empty())
        {
            const SchedEvent *nxt = &ev.front(); // nothing later this week = wrap
            for (const auto &e : ev)
                if (e.at > nowAt)
                {
                    nxt = &e;
                    break;
                }
            n.at = nxt->at;
            n.on = nxt->on;
            n.idx = nxt->idx;
        }
        g_next[i] = n;
    }
}

// Fire the events due this minute. Checked once per minute change, so each
// event fires exactly once.
void serviceSchedules()
{
    struct tm tmNow;
    if (!localNow(tmNow))
        return;
    static int lastAt = -1;
    int nowAt = weekMinute(tmNow);
    if (nowAt == lastAt)
        return;
    lastAt = nowAt;
    refreshNextInfo(nowAt);

    bool changed = false;
    for (uint8_t i = 0; i < NUM_PORTS; i++)
    {
        for (const auto &e : g_evCache[i])
        {
            if (e.at != nowAt)
                continue;
            ports[i].setEnabled(e.on);
            Serial.printf("[sched] port %u -> %s\n", i + 1, e.on ? "on" : "off");

            // A one-shot entry disables itself after its LAST event — for an
            // entry with a window that's the closing OFF, so the window runs.
            const auto &entry = g_schedules.config().ports[i][e.idx];
            bool hasWindow = entry.on && hubEntryWindow(entry) > 0;
            if (entry.once && (!hasWindow || e.tail))
            {
                Serial.printf("[sched] port %u: one-shot fired, entry disabled\n", i + 1);
                g_schedules.disableEntry(i, e.idx);
                changed = true;
                break; // this port's events are stale now; rebuilt next pass
            }
        }
    }
    if (changed)
    {
        g_schedules.validate();
        config.save();
    }
}

// Put every scheduled port into the state its schedule says it should be in
// right now, from its most recent past event. Without this a hub that
// rebooted after a scheduled ON would stay off until the next event. Runs once,
// as soon as the clock is synced. Ports with no schedule keep their
// power-on-boot state.
void reconcileSchedules()
{
    struct tm tmNow;
    if (!localNow(tmNow))
        return;
    int nowAt = weekMinute(tmNow);
    for (uint8_t i = 0; i < NUM_PORTS; i++)
    {
        const auto &ev = g_evCache[i];
        if (ev.empty())
            continue;
        // The last event at or before now; if there's none this week, the
        // week wraps and its final event is the one in force.
        const SchedEvent *best = &ev.back();
        for (const auto &e : ev)
        {
            if (e.at > nowAt)
                break;
            best = &e;
        }
        ports[i].setEnabled(best->on);
        Serial.printf("[sched] catch-up: port %u -> %s (last due %d min ago)\n", i + 1,
                      best->on ? "on" : "off", (nowAt - best->at + 10080) % 10080);
    }
}

// A port's next scheduled change, ready to report.
struct NextChange
{
    bool valid = false; // false = nothing scheduled, or the clock isn't synced
    int mins = 0;       // minutes from now
    int secs = 0;       // seconds from now, for countdowns
    bool on = false;    // what it will do
    char at[16] = "";   // when, as "Ddd HH:MM"
    int entry = -1;     // the schedule entry responsible
};

NextChange nextChange(uint8_t i)
{
    NextChange c;
    struct tm tmNow;
    const NextInfo &n = g_next[i];
    if (n.at < 0 || !localNow(tmNow))
        return c;
    c.valid = true;
    c.mins = n.at - weekMinute(tmNow);
    if (c.mins <= 0)
        c.mins += 10080; // next week
    c.secs = max(0, c.mins * 60 - tmNow.tm_sec);
    c.on = n.on;
    c.entry = n.idx;
    snprintf(c.at, sizeof(c.at), "%s %02d:%02d", DOW_NAME[n.at / 1440], (n.at % 1440) / 60, n.at % 60);
    return c;
}
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
void loop()
{
    processSerial();
    ArduinoOTA.handle();

    // ---- network ----
    if (g_gotIP)
    {
        g_gotIP = false;
        startNetServices();
    }
    if (g_wifi.consumeChanged()) // WiFi settings edited — reconnect with them
        connectWiFi();
    serviceWiFi();

    // ---- port hardware ----
    if (g_expanderIrq)
    {
        g_expanderIrq = false;
        serviceExpander();
    }
    for (auto &port : ports)
        if (port.senseDirty())
            port.serviceSense();

    // ---- settings groups (location lookup) and scheduler ----
    HubRegistry::dispatchLoop();

    bool scheduleChanged = (g_schedules.version() != g_evCacheVer);
    refreshEventCache();
    // As soon as the clock is valid, put ports where their schedules say they
    // should be — covers changes missed while the hub was off.
    static bool reconciled = false;
    if (!reconciled && timeSynced())
    {
        reconciled = true;
        reconcileSchedules();
        scheduleChanged = true;
    }
    struct tm tmNow;
    if (scheduleChanged && localNow(tmNow))
        refreshNextInfo(weekMinute(tmNow));
    serviceSchedules();

    // ---- temperature: every 2 s (the sensor needs >= 1 s between reads) ----
    static uint32_t lastTemp = 0;
    if (g_ahtOk && millis() - lastTemp >= 2000)
    {
        lastTemp = millis();
        if (aht.read() == DHT20_OK)
        {
            g_tempC = aht.getTemperature();
            g_humid = aht.getHumidity();
            g_tempValid = true;
        }
    }

    // ---- button: each press flips every port to its opposite state ----
    static int lastBtn = LOW;
    static uint32_t lastBtnMs = 0;
    int btn = digitalRead(BUTTON_PIN);
    if (btn != lastBtn && millis() - lastBtnMs > 30) // 30 ms debounce
    {
        lastBtnMs = millis();
        lastBtn = btn;
        if (btn == HIGH)
            for (auto &port : ports)
                port.setEnabled(!port.isEnabled());
    }

    // ---- LEDs at ~50 fps: boot sweep first, then the port states ----
    static uint32_t lastFrame = 0;
    uint32_t now = millis();
    if (now - lastFrame >= 20)
    {
        lastFrame = now;
        if (!renderBootSweep())
            renderLeds();
    }
}

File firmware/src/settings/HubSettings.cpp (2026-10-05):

// SPDX-License-Identifier: GPL-3.0-or-later
// Copyright (c) 2026 Unexpected Maker
//
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
// HubSettings.cpp — the settings registry, /settings.json storage, and every
// settings group: their web form fields and the behaviour a few of them carry
// (timezone + location lookup, WiFi change detection, schedule validation).
#include "HubSettings.h"
#include <LittleFS.h>
#include <HTTPClient.h>
#include <string.h>
#include <time.h>

static const char *SETTINGS_PATH = "/settings.json";

// ---- HubRegistry ---------------------------------------------------------

// The list lives in a function-static so it exists before any group's
// constructor runs, whatever order the globals are initialised in.
static std::vector<HubSettings *> &registry()
{
    static std::vector<HubSettings *> v;
    return v;
}

void HubRegistry::add(HubSettings *m)
{
    if (m)
        registry().push_back(m);
}

const std::vector<HubSettings *> &HubRegistry::all() { return registry(); }

HubSettings *HubRegistry::get(const char *name)
{
    if (!name)
        return nullptr;
    for (auto *m : registry())
        if (strcmp(m->name(), name) == 0)
            return m;
    return nullptr;
}

void HubRegistry::dispatchNetUp(const char *ip)
{
    for (auto *m : registry())
        m->onNetUp(ip);
}

void HubRegistry::dispatchLoop()
{
    for (auto *m : registry())
        m->loop();
}

void HubRegistry::dispatchConfigChanged(const char *name)
{
    if (HubSettings *m = get(name))
        m->onConfigChanged();
}

// ---- HubConfig -----------------------------------------------------------

bool HubConfig::begin()
{
    for (auto *m : HubRegistry::all())
        m->bind(*this);
    if (!LittleFS.begin(true)) // true = format if it won't mount
    {
        Serial.println("[config] LittleFS mount failed — settings will not persist");
        return false;
    }
    _fs_ready = true;
    return load();
}

bool HubConfig::load()
{
    if (!_fs_ready)
        return false;

    nlohmann::json settings;
    bool have = false;
    File f = LittleFS.open(SETTINGS_PATH, "r");
    if (f)
    {
        String content = f.readString();
        f.close();
        try
        {
            settings = nlohmann::json::parse(content.c_str());
            have = settings.is_object();
        }
        catch (...)
        {
            Serial.printf("[config] %s is corrupt — using defaults\n", SETTINGS_PATH);
        }
    }

    // Each group gets its own entry, or an empty object (= struct defaults).
    // A group whose stored entry won't parse falls back to defaults on its own
    // without affecting the others.
    for (auto *m : HubRegistry::all())
    {
        try
        {
            m->fromJson(have && settings.contains(m->name()) ? settings[m->name()]
                                                             : nlohmann::json::object());
        }
        catch (...)
        {
            Serial.printf("[config] '%s' settings unreadable — using defaults\n", m->name());
            m->fromJson(nlohmann::json::object());
        }
    }
    Serial.printf("[config] settings loaded%s\n", have ? "" : " (defaults)");
    return true;
}

bool HubConfig::save()
{
    if (!_fs_ready)
        return false;
    nlohmann::json j = nlohmann::json::object();
    for (auto *m : HubRegistry::all())
    {
        nlohmann::json mj;
        m->toJson(mj);
        j[m->name()] = mj;
    }
    std::string content = j.dump(2);
    File f = LittleFS.open(SETTINGS_PATH, "w");
    if (!f)
        return false;
    f.write((const uint8_t *)content.data(), content.size());
    f.close();
    return true;
}

// ###########################################################################
// The settings groups
// ###########################################################################

DeviceSettings g_device;
WiFiSettings g_wifi;
LocationSettings g_location;
LedsSettings g_leds;
PortsSettings g_ports;
WebsiteSettings g_website;
SchedulesSettings g_schedules;

// Shorthand for building form fields.
using F = HubSettingField;

// ===========================================================================
// device
// ===========================================================================

std::vector<HubSettingField> DeviceSettings::uiSchema()
{
    return {
        {.type = F::T::String, .key = "device_name", .label = "Device name"},
        {.type = F::T::String, .key = "hostname", .label = "Hostname",
         .help = "Reach the hub at <hostname>.local. Takes effect after a restart."},
    };
}

String DeviceSettings::hostname() const
{
    String out;
    for (char c : _config.hostname)
    {
        if (c >= 'A' && c <= 'Z')
            c = c - 'A' + 'a';
        bool ok = (c >= 'a' && c <= 'z') || (c >= '0' && c <= '9') || c == '-';
        if (ok && !(c == '-' && out.length() == 0) && out.length() < 32)
            out += c;
    }
    while (out.endsWith("-"))
        out.remove(out.length() - 1);
    return out.length() ? out : String("usb-hub");
}
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

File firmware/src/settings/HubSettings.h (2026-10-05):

// SPDX-License-Identifier: GPL-3.0-or-later
// Copyright (c) 2026 Unexpected Maker
//
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
// HubSettings.h — everything the hub stores in flash.
//
// Every persisted setting lives in a "settings group": a small class that owns
// a plain config struct. The first half of this file is the machinery the
// groups are built on:
//
//   HubSettings / HubSettingsT<T>  base class for a group. A group declares
//                                  its config struct, a name, a label, and the
//                                  list of fields the web Settings drawer
//                                  should show. JSON conversion is automatic.
//   HubRegistry                    every group registers itself on
//                                  construction, so storage, the web UI and the
//                                  lifecycle hooks can walk them all without a
//                                  hand-maintained list.
//   HubConfig                      loads and saves every group to a single
//                                  /settings.json on LittleFS.
//
// The second half is the groups themselves, each stored under its name():
//
//   device     g_device     display name and network hostname
//   wifi       g_wifi       credentials and DHCP / static addressing
//   location   g_location   city, UTC offset and NTP server
//   leds       g_leds       port LED on/off and brightness
//   ports      g_ports      which ports power up at boot
//   website    g_website    web UI theme
//   schedules  g_schedules  per-port power schedules, plus their validation
#pragma once
#include <Arduino.h>
#include <array>
#include <vector>
#include "json.h"

// ---- Arduino String <-> JSON -------------------------------------------
// Lets config structs use Arduino String fields directly with nlohmann's
// NLOHMANN_DEFINE_TYPE_* macros.
inline void to_json(nlohmann::json &j, const String &value) { j = value.c_str(); }
inline void from_json(const nlohmann::json &j, String &s) { s = j.get_ptr<const std::string *>()->c_str(); }

// One field in a group's web form. The values themselves come from the
// group's config struct; this only describes how to present them.
struct HubSettingField
{
    enum class T
    {
        Bool,   // on/off button
        Int,    // number box, bounded by min/max, stepping by step
        String  // text box (masked automatically if the key looks secret)
    };
    T type;
    const char *key;            // JSON key inside the group's config
    const char *label;          // shown to the user
    long min = 0;               // Int only
    long max = 0;               // Int only
    long step = 1;              // Int only
    const char *help = nullptr; // optional one-line hint shown under the field
};

class HubConfig;

// Base for every settings group. Use HubSettingsT<ConfigT> rather than this
// directly — it supplies the JSON conversion and self-registration.
class HubSettings
{
public:
    virtual ~HubSettings() = default;

    // Gives the group a way to persist its own changes (e.g. the IP-geo lookup
    // filling in a location). Called for every group by HubConfig::begin().
    void bind(HubConfig &cfg) { _cfg = &cfg; }

    // Unique key in /settings.json and in the settings API.
    virtual const char *name() const = 0;
    // Heading shown in the web Settings drawer.
    virtual const char *label() const = 0;
    // False hides the group from the Settings drawer (it is still stored).
    virtual bool show_on_website() const { return true; }

    virtual void toJson(nlohmann::json &j) const = 0;
    virtual void fromJson(const nlohmann::json &j) = 0;
    // Fields to show in the Settings drawer, in display order.
    virtual std::vector<HubSettingField> uiSchema() { return {}; }

    // ---- Lifecycle hooks (called via HubRegistry) ----
    // The network came up with this IP.
    virtual void onNetUp(const char *ip) {}
    // This group's values were just changed from the web UI.
    virtual void onConfigChanged() {}
    // Called every pass of the main loop.
    virtual void loop() {}

protected:
    HubConfig *_cfg = nullptr;
};

// Global list of settings groups, filled as each group is constructed.
class HubRegistry
{
public:
    static void add(HubSettings *m);
    static const std::vector<HubSettings *> &all();
    // Look a group up by name(); nullptr if there is none.
    static HubSettings *get(const char *name);

    // Fan a lifecycle event out to every group.
    static void dispatchNetUp(const char *ip);
    static void dispatchLoop();
    static void dispatchConfigChanged(const char *name);
};
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

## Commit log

2026-10-11 Port profiler, auto power on connect, I2C bus lock
    - Port profiler: profilerStart(), profilerStop(), profilerGetPort(),
    profilerSetAveraging(). Samples V and I on every powered port at 100 Hz
    into an 8-sample ring buffer per port.
    - Per-port auto power on connect: a port powers on when a device is
    plugged in and off when it's unplugged.
    - Power on boot and auto power on connect are set per port in the
    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
2026-10-11 Per-port power mode
    - power_mode per port: "manual", "boot" or "connect". Replaces
    power_on_boot and auto_power_on_connect, so a port can only be in one
    mode. Settings saved by 1.1.0 (power_on_boot) load as "boot".
    - Settings panel: Power on boot and Auto power on connect rows; turning
    a port on in one row turns it off in the other. M in the Ports heading
    marks manual ports.
    - Docs: API reference and coding conventions updated.
2026-10-12 Full-resolution readings, R3 schematic
    Volts are shown to 3 dp (8 mV steps) in the API, info and web UI. The web
    UI shows mA and mW to 1 dp (0.4 mA steps) instead of whole numbers.
    rest_api.md examples updated to match.
    Add the R3 schematic PDF to hardware/.
2026-10-14 Port history rework: 100 Hz PSRAM history, binary pages, new graph
    Firmware
    - Profiler always runs from boot and is the only writer of the history. It
    writes every port's raw INA3221 reading into PSRAM every 10 ms: 60 minutes
    per port, 3 bytes per reading, invalid slots for off ports, missing monitors,
    failed reads and missed periods.
    - Port events (power off/on, device removed/inserted) recorded per port.
    - All port readings (status, REST, serial info/mon) come from the history,
    with the averaging setting applied when read.
    - /api/history now sends binary pages of up to 10 minutes: newest first, older
    pages to backfill, and newer readings for live updates. Bad port or
    parameter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
2026-10-14 Firmware 2.0.0: graph scales and measurements, REST history, profiler fixes
    Graph
    - Y scale columns: hover tint, double-click to fit what's in view, drag to
    move, scroll to stretch around the average in view. Scales clamped to 0
    and the hub's limits (6 V, 1802 mA), with padding.
    - Readings grouped in blocks lined up on the capture count, so the live view
    doesn't shimmer.
    - Missing readings shaded red, except while the port was switched off.
    Missing-data legend; Head is now an indicator.
    - Cursor dots on each line; rounded cursor info box.
    - Measurements box (min / max / avg of what's in view) while zoomed in.
    - Event labels stack instead of overlapping.
    - Averaging buttons add 16; av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
2026-10-14 Graph legend at top right; favicon with transparent corners
    - Voltage / Current / Power legend moved from under the graph to the top
    right, next to Missing data, with the same swatch shape. The old legend
    styles are marked historical.
    - Favicon PNGs and ICO regenerated with transparent rounded corners (they
    had opaque white corners, showing as a square in Brave).
2026-10-14 Docs: bring graph, REST API and profiler docs up to date
    - graph_history.md: feature list rewritten for the current graph (view
    buttons, blocks and spike band, missing-data shading, legend and Head,
    zoom and brush, cursor, Y scale columns, measurements, mini graphs).
    - rest_api.md: power modes apply as soon as they're set; settings example
    without the historical graph settings; icon routes listed.
    - profiler.md: task priority, missed/failed counts in serial info, and
    delays hidden in library calls (AHT20) under the I2C lock.
2026-10-15 ESPHome native API for Home Assistant
    Each port shows up in Home Assistant as a power switch, a
    device-connected sensor and a current sensor. Off by default; turned
    on under Home Assistant in Settings.
2026-10-15 ESPHome: PSRAM buffers, non-blocking sockets
    Frame and receive buffers allocated once in PSRAM, nothing allocated
    per message, non-blocking sends that drop a stalled client, 60 s
    dead-client timeout, API 1.12 to match 2025.10.0, live friendly name.
2026-10-15 Coding conventions: memory and network rules
    PSRAM for buffers, allocate once at start-up, non-blocking sockets in
    the main loop, dead-client timeouts, and lwIP's 16-segment send queue.
2026-10-15 ESPHome: ping quiet clients before dropping them
    Home Assistant only pings when it hasn't heard from the device, so with
    state updates flowing it went quiet and was dropped after 60 s. The hub
    now pings a client that's been quiet for 20 s and drops it after 60 s
    of silence.
2026-10-15 ESPHome: retry when the socket can't listen
    start() only marks the API running once the socket is listening. If
    bind or listen fails it stays stopped and tries again 5 s later,
    instead of waiting for the setting to be toggled.
2026-10-15 ESPHome: comment the send functions, clamp formatted lengths
    Every send function has its comment, and a small format() helper
    returns the length actually written, so a string length can never run
    past its buffer.
2026-10-16 Firmware 2.1.0
    - Find a port: magnifier on each port card flashes its LED three times;
    POST /api/identify?n=1-6
    - Reverse port order setting: numbers the cards 1-6 left to right
    - Show time 24 hour setting: 12 hour sidebar clock with AM/PM
    - Mini graph metric per port; Shift-click sets every port
    - Port card number in the corner, name centred; own hover for the mini
    graph and power toggle
    - Schedule view button is a calendar; Settings closes on save
    - SettingsLock: settings locked between the web server and the main loop
    - Version 2.1.0
2026-10-16 ESPHome: temperature and humidity sensors
    The hub's AHT20 readings show up in Home Assistant as Temperature (°C)
    and Humidity (%). They're missing until the sensor has a first reading,
    and are sent when they change by 0.1, checked with the port currents.
2026-10-23 Don't block on serial when nothing's reading it
    With USB plugged in but no serial reader, each Serial.print waited up
    to ~2 s. loop() prints while holding SettingsLock, so a web request
    waiting on the lock tripped AsyncTCP's 5 s task watchdog about 19 s
    after boot. Serial.setTxTimeoutMs(0) drops the output instead.
2026-10-23 Firmware 2.2.0
    - Port cards UI overhaul
    - Total current and power graphs in the sidebar Power panel
    - Mini graphs hold still as they move and follow the averaging setting
    - Fixed TASK_WDT reboots when USB serial isn't being read (#7, thanks
    @infamy), plus a 4 KB serial transmit buffer so output isn't lost while
    a monitor is reading
    - Version 2.2.0
2026-11-11 Case V2
    No supports needed, guides hold the light pipes straight without glue,
    and the bottom has extra PCB support and more tolerance for the board
    outline.

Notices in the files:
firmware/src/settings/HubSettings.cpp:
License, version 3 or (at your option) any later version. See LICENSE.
